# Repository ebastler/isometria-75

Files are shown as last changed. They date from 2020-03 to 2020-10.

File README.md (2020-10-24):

# isometria<sup>75</sup>

The first prototype is sitting on my desk and works perfectly - clearance for weights and battery is currently wrong, so the intended battery will not fit in the case.

----
 
 The name isometria<sup>75</sup> has it's origin in the greek noun ἰσομετρία (in latin letters: isometria), meaning "equality of measure" [[1]](http://perseus.uchicago.edu/cgi-bin/philologic/getobject.pl?c.35:6:59.LSJ). This word ended up being included in various languages, among them english (isometric), with the same meaning. I chose it for two reasons - because this keyboard is only available in an ISO layout (sorry ANSI users - for once it is ne ANSI avail), but also, because I paid attention to only use u/4 spaces throughout my board. You will have a hard time finding any distance on it that's not a multiple of 4.75 mm.

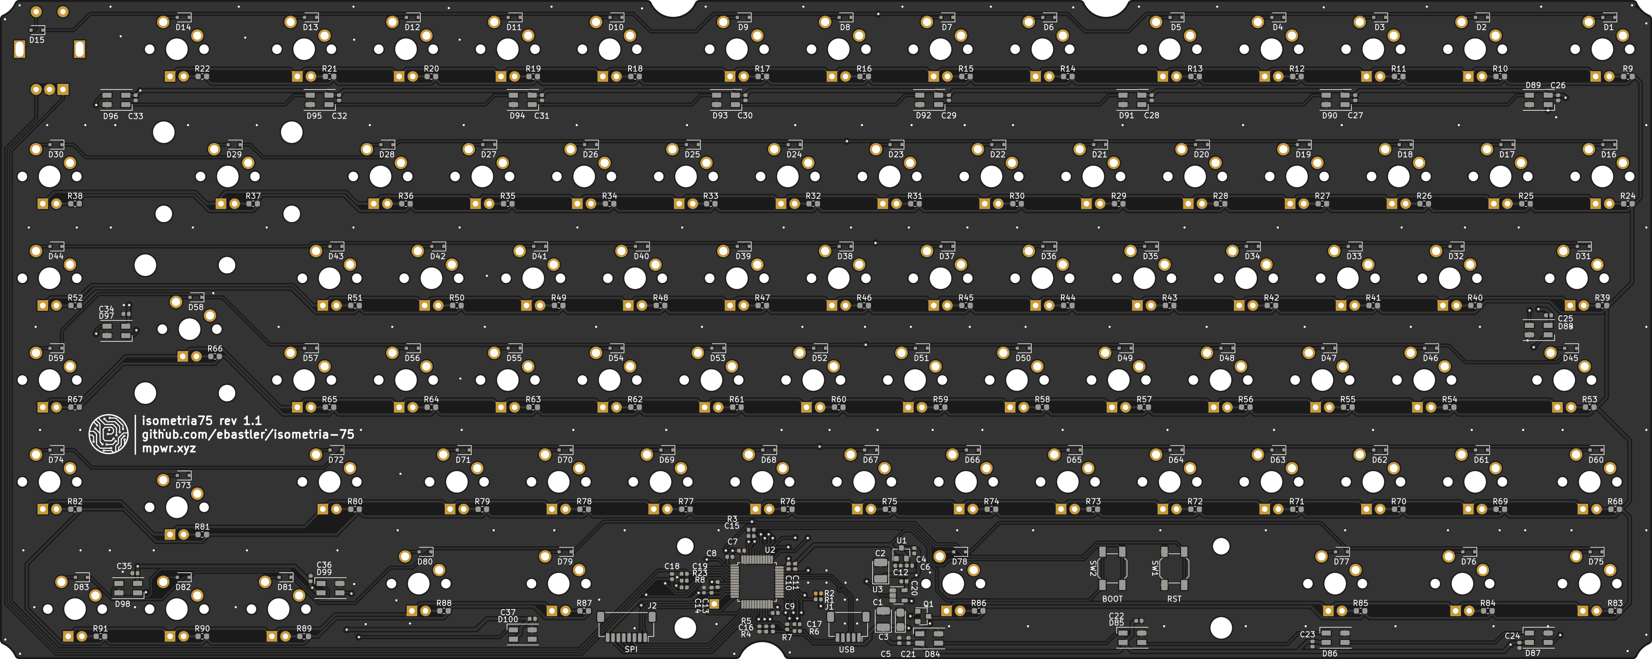
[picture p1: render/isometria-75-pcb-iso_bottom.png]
pcb_bottom
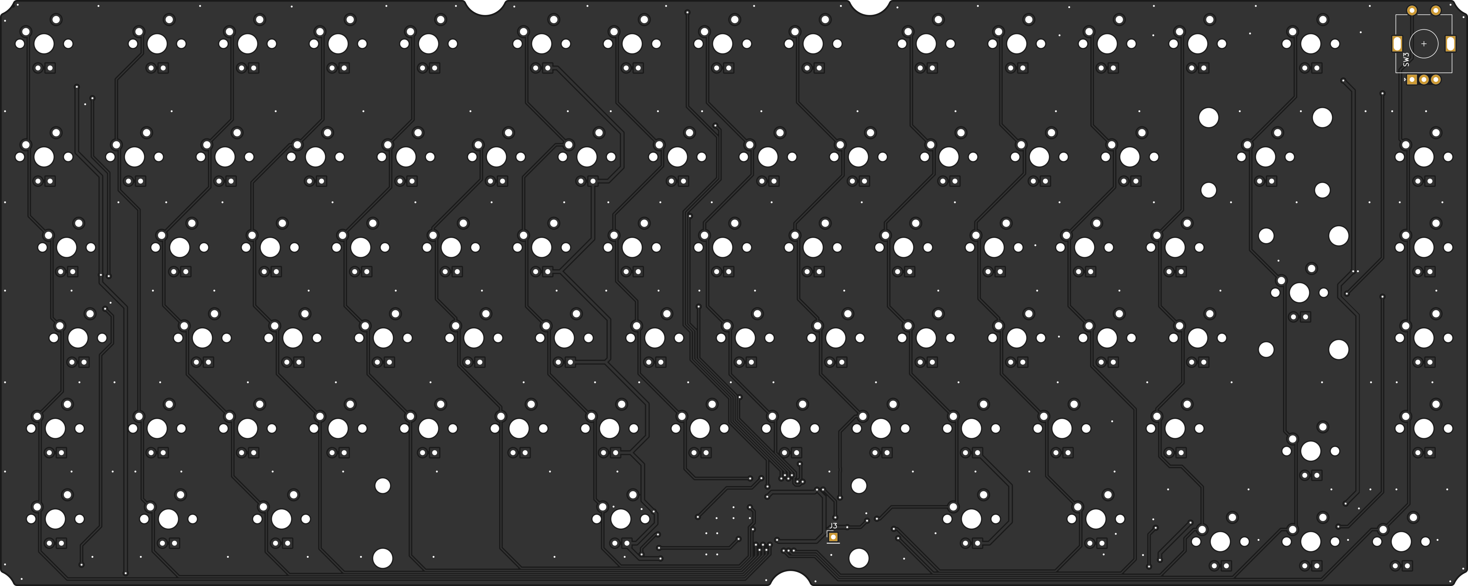
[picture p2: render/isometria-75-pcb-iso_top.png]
pcb_top
|||
|:---:|:---:|
|overview_top|detail_top|
|overview_rearside|overview_side|

 ## Features
 * CNC'd top shell with integrated 3 mm plate (obviously, with cutouts for switch retention and PCB mount stabs)
 * 6.8° typing angle
 * The PCB is equipped to fit 82 cherry MX-style switches
 * One 3 mm LED per switch (monochrome, dimmable only as one group)
 * 17 SK6812 Mini can be soldered to the bottom of the board for underglow
 * Fits either a battery-management or a simple USB-C daughterboard ([Repo link](https://github.com/ebastler/unified-usb-pcb))
 * A rotary encoder sits in the top right corner and the push-button is wired to the controller (Row 0 Column 15)
 * The USB-C connector is placed on a small PCB on it's own, which can be replaced by a battery management board
 * Sense wires to measure the input voltage and to check if the battery is currently being charged
 * A STM32F072CBT6 controller with native crystal-less USB and a lot of IO for various things
 * An SPI interface is wired to a second connector, allowing for a SPI Bluetooth LE board to be added
 * One leftover GPIO is available on a header - if you want to add something yourself

## Design
The PCB uses a key spacing of 19 mm (instead of the default 19.05), and all delimiters between key-blocks, or keys and the border of the case are 4.75 or 9.5 mm wide. This allows for a pleasantly homogenous design, which earned the keyboard it's name. Sadly, this layout requires a 1.5u right shift, which very few sets include. 

The bottom shell breaks the minimalist design of the top shell a little, with "stepped" faces. While the design originated from the need to make it easily millable on a 3 axis CNC, I appreciate the fact that it makes the board visually a bit more interesting.

## Geekhack project thread
https://geekhack.org/index.php?topic=106060.msg2896354

## FAQ:
 * Where can I buy this?

   I'm afraid there will not be any groupbuy nor will it be stocked at some reseller - All files are open source though, feel free to order a batch of PCBs and a case yourself - or improve it!

 * When will there be an ANSI version?

   Even though I planned not to do ANSI, I actually went with multi-layout for v2! Stay tuned!

 * Why did you clone the Evolv/Satisfaction?
 
   I made my own design choices, and designed everything from scratch - however the evolv heavily influenced my design. I fell in love with it the first time I saw it, but it had a few things I dislike. So I decided to mostly adopt it's layout with some changes, and design a case which follows my design ideals - ending up with a (visually) very similar top enclosure - The standalone-features of the evolv are it's premium materials, construction and generative design, and I did not include either.

For any other questions, or problems with my board (if you decided to build one yourself) - feel free to contact me. I'm idling around and occasionally check my PMs on freenode (ebastler), am active on reddit (the_ebastler) and on discord (ebastler#8966).

## Big thanks to:
 - ai03 for both his [great tutorial](https://wiki.ai03.me/books/pcb-design/chapter/pcb-designer-guide) as well as his various footprints I used in my design - I don't know if I had been able to design this without his help.
 - The awesome people on grabcad for the [MX switch](https://grabcad.com/library/cherry-mx-switches-mx-1), [Cherry Stab](https://grabcad.com/library/cherry-mx-stabilizer-mx-1) and [pushbutton](https://grabcad.com/library/5mm-button-switch-1) models, [JST SH models](https://grabcad.com/library/jst-sh-smd-connectors-1/details?folder_id=3903823) and [WS2812 Mini models](https://grabcad.com/library/smd-ws2812b-led-1) which made my design a whole lot easier, and my renders prettier.
  - People on the MechKeys and Mechanische Tastaturen Deutschland discord servers who tirelessly answered my questions - from the noobiest to the most complicated ones.
  - [Propagandalf1](https://github.com/Propagandalf1) for all the advise, criticism and ideas for improvement
  - Pseudoephedrin and Lux for checking my PCB layouts for errors
  - Hendrik for milling my proto

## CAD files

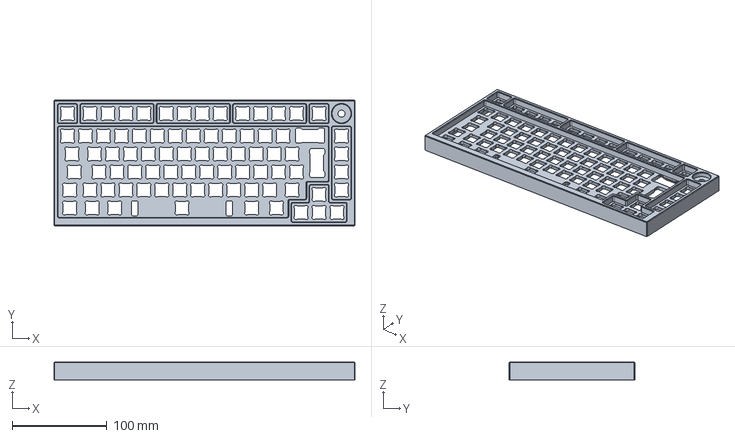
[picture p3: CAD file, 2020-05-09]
isometria-75-case-iso/fab/isometria-75-top.step
318.2 x 133.0 x 19.0 mm

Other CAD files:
isometria-75-case-iso/fab/isometria-75-bottom.step

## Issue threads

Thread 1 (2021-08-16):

BOM and CPL Files in XLS, XLSX or in CSV format

Ardakilic, 2021-08-16:
Hello,

I want to print the PCB from JLCPCB, however, the BOM format on the repository is in XML format, which is not accepted by them.

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

Can you share the BOM and CPL files in a way which JLCPCB can understand please, so I can get the PCB's SMD components such as IC pre-assembled?

Thanks, kind regards,

Closed 2021-08-17.

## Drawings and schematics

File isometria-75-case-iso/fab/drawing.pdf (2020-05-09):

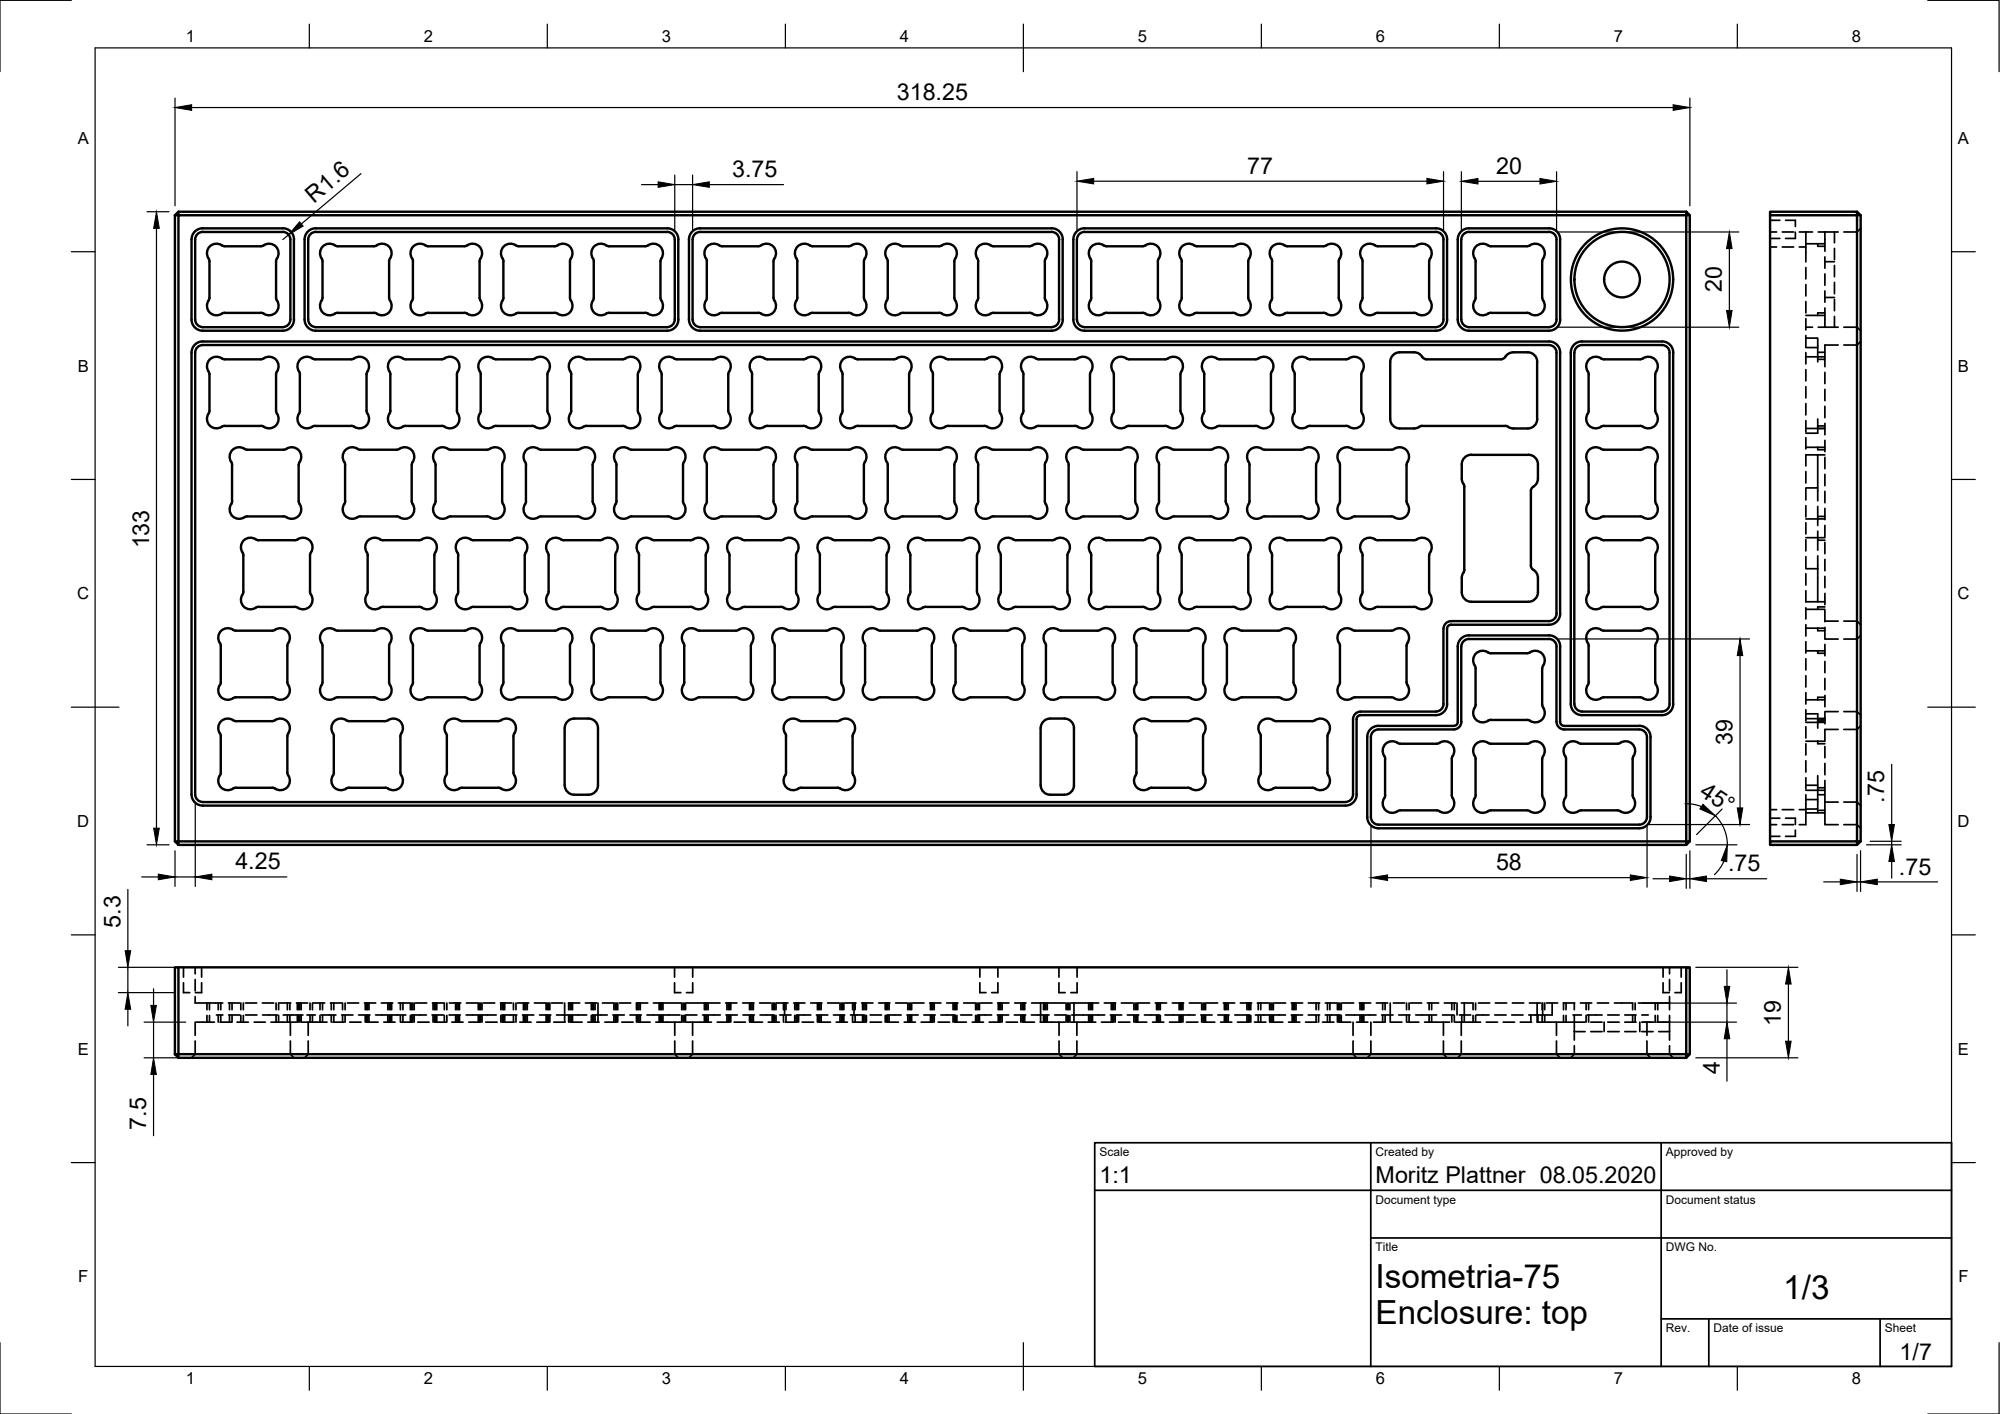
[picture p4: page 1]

Scale 1:1 | Created by Moritz Plattner 08.05.2020 | Approved by

Document type | Document status

Title Enclosure: top | DWG No. 1/3 Isometria-75

Rev. | Date of issue | Sheet

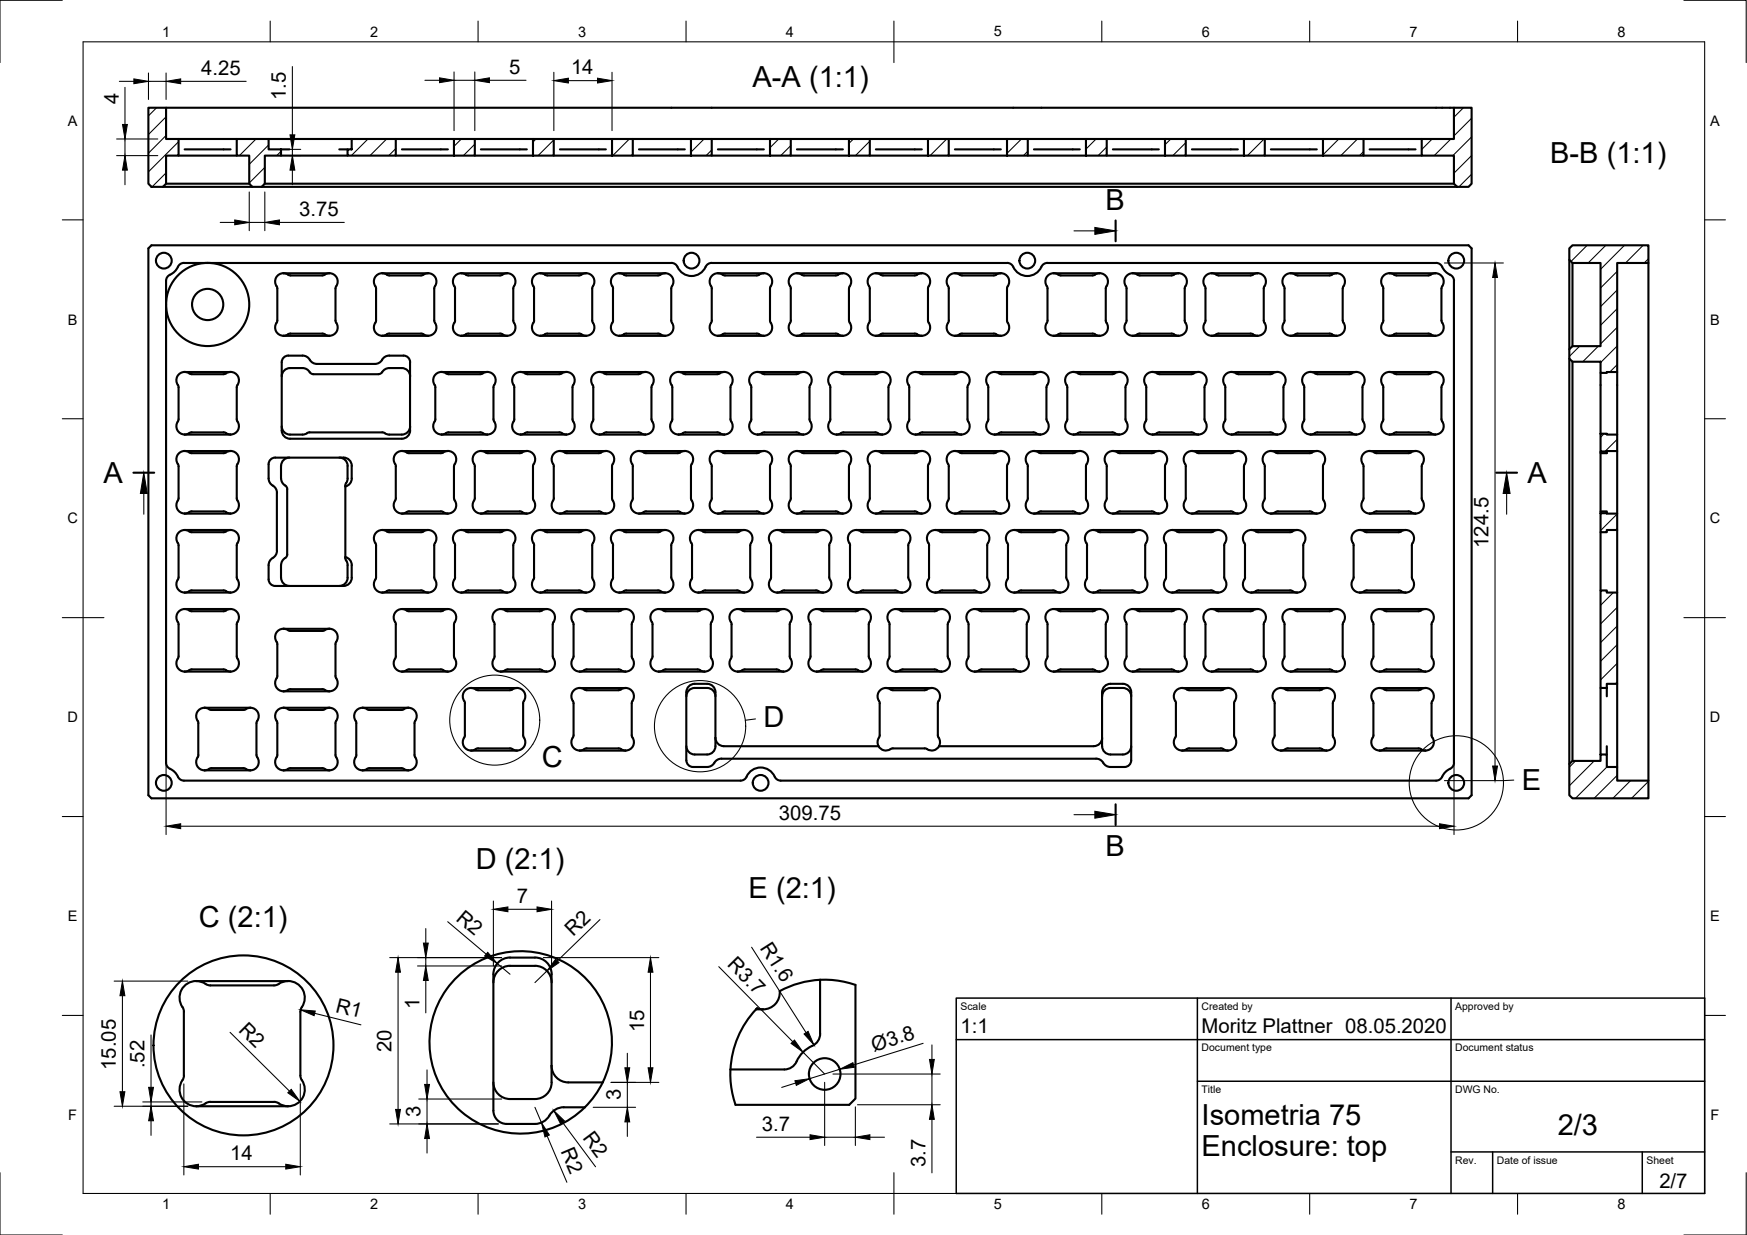
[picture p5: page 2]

Scale 1:1 | Created by Moritz Plattner 08.05.2020 | Approved by

Document type | Document status

Title | DWG No. 2/3 Isometria 75

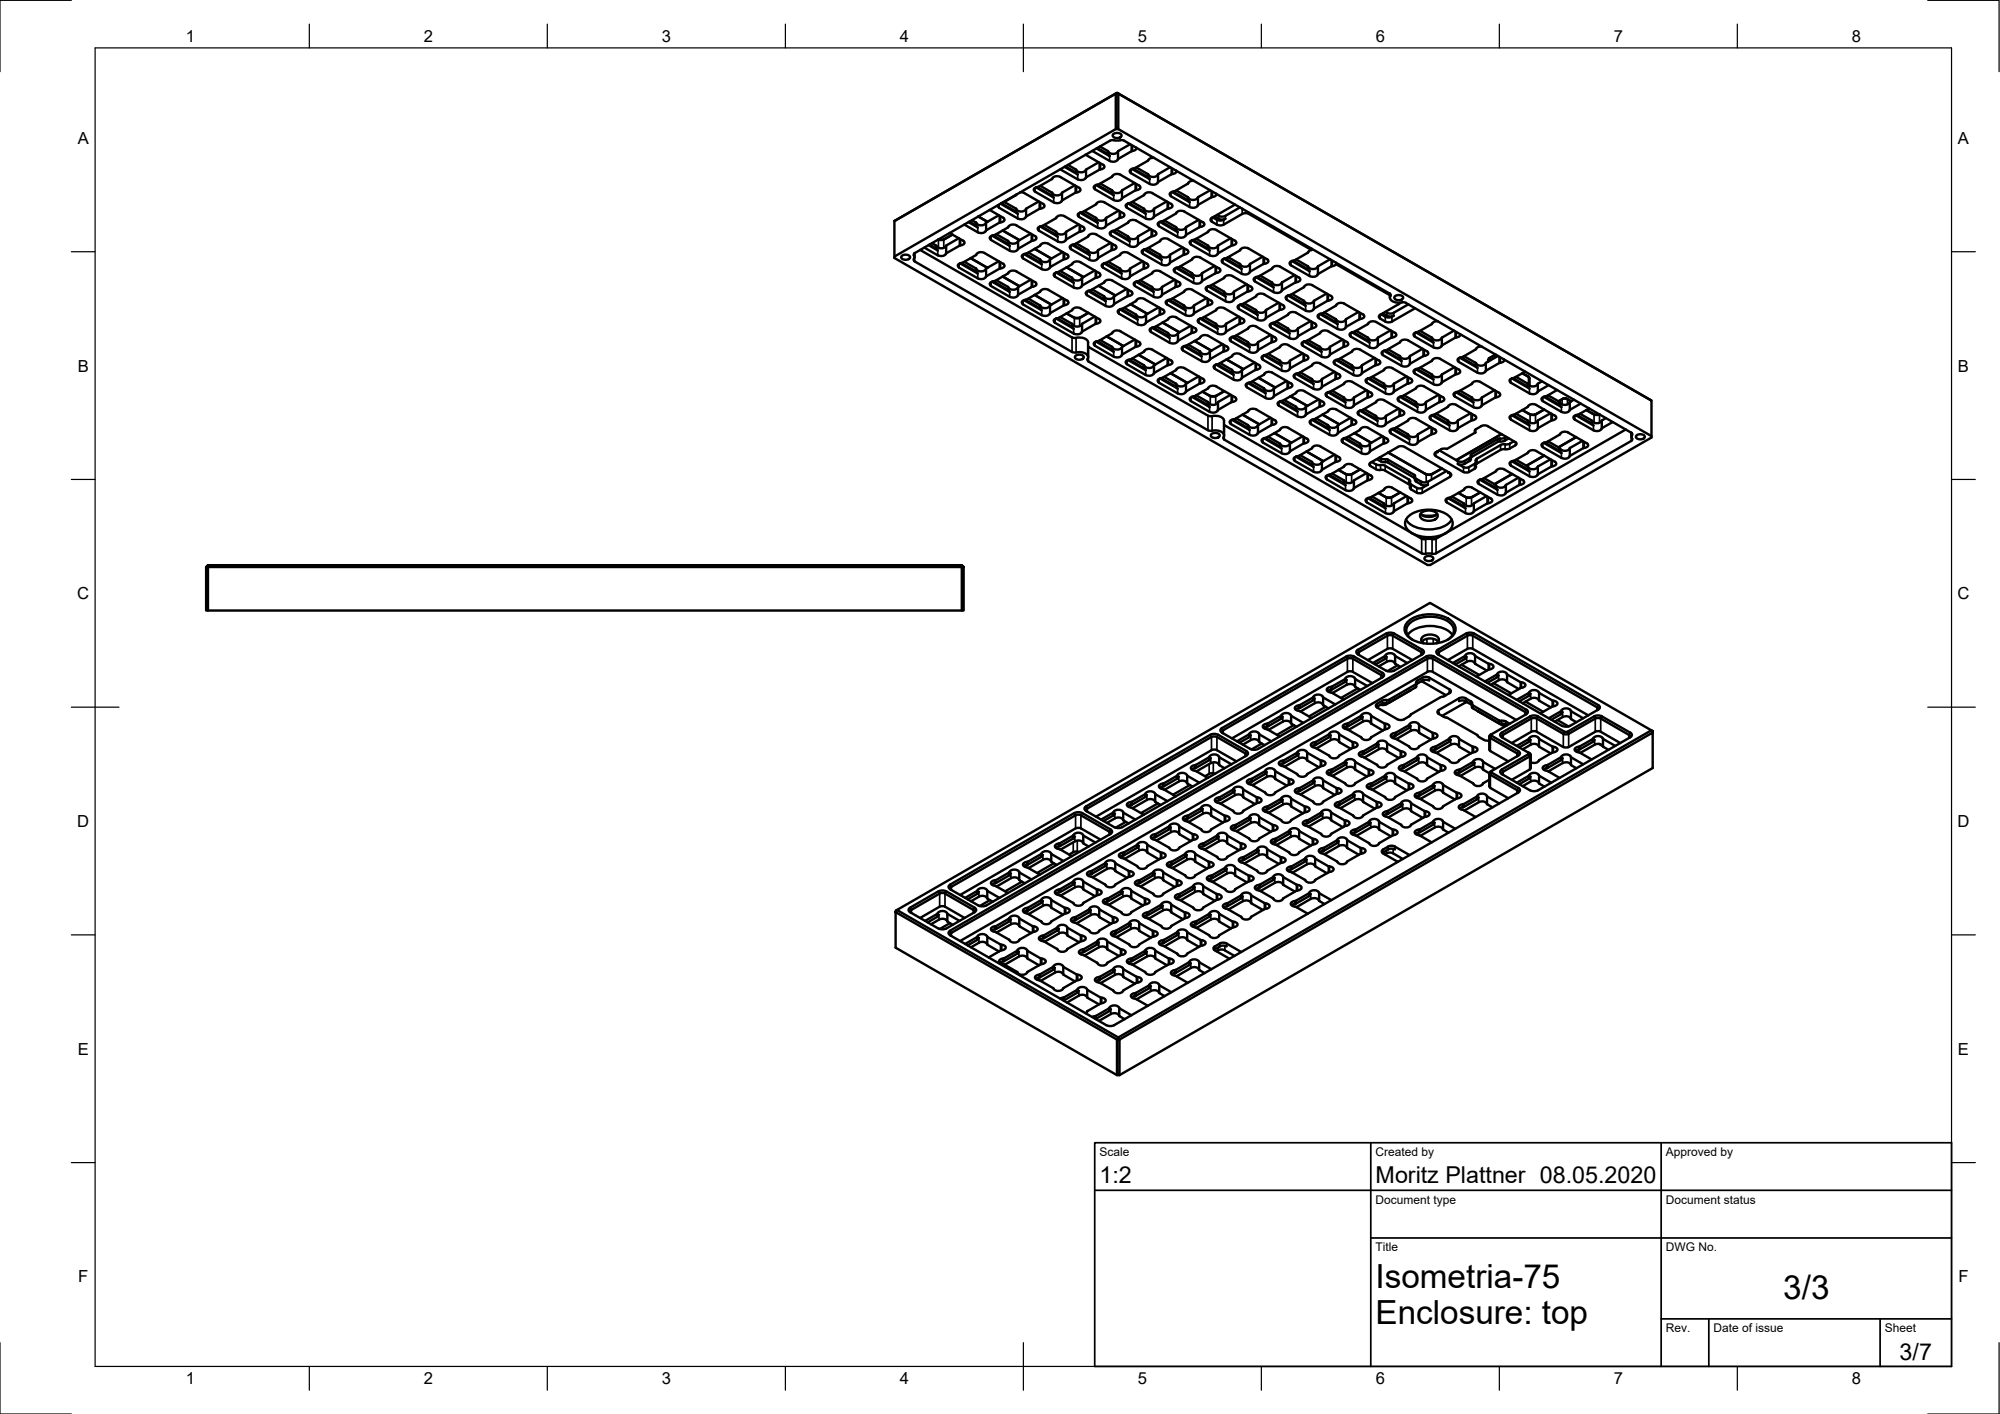
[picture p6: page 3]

Scale 1:2 | Created by Moritz Plattner 08.05.2020 | Approved by

Document type | Document status

Title | DWG No. 3/3 Isometria-75

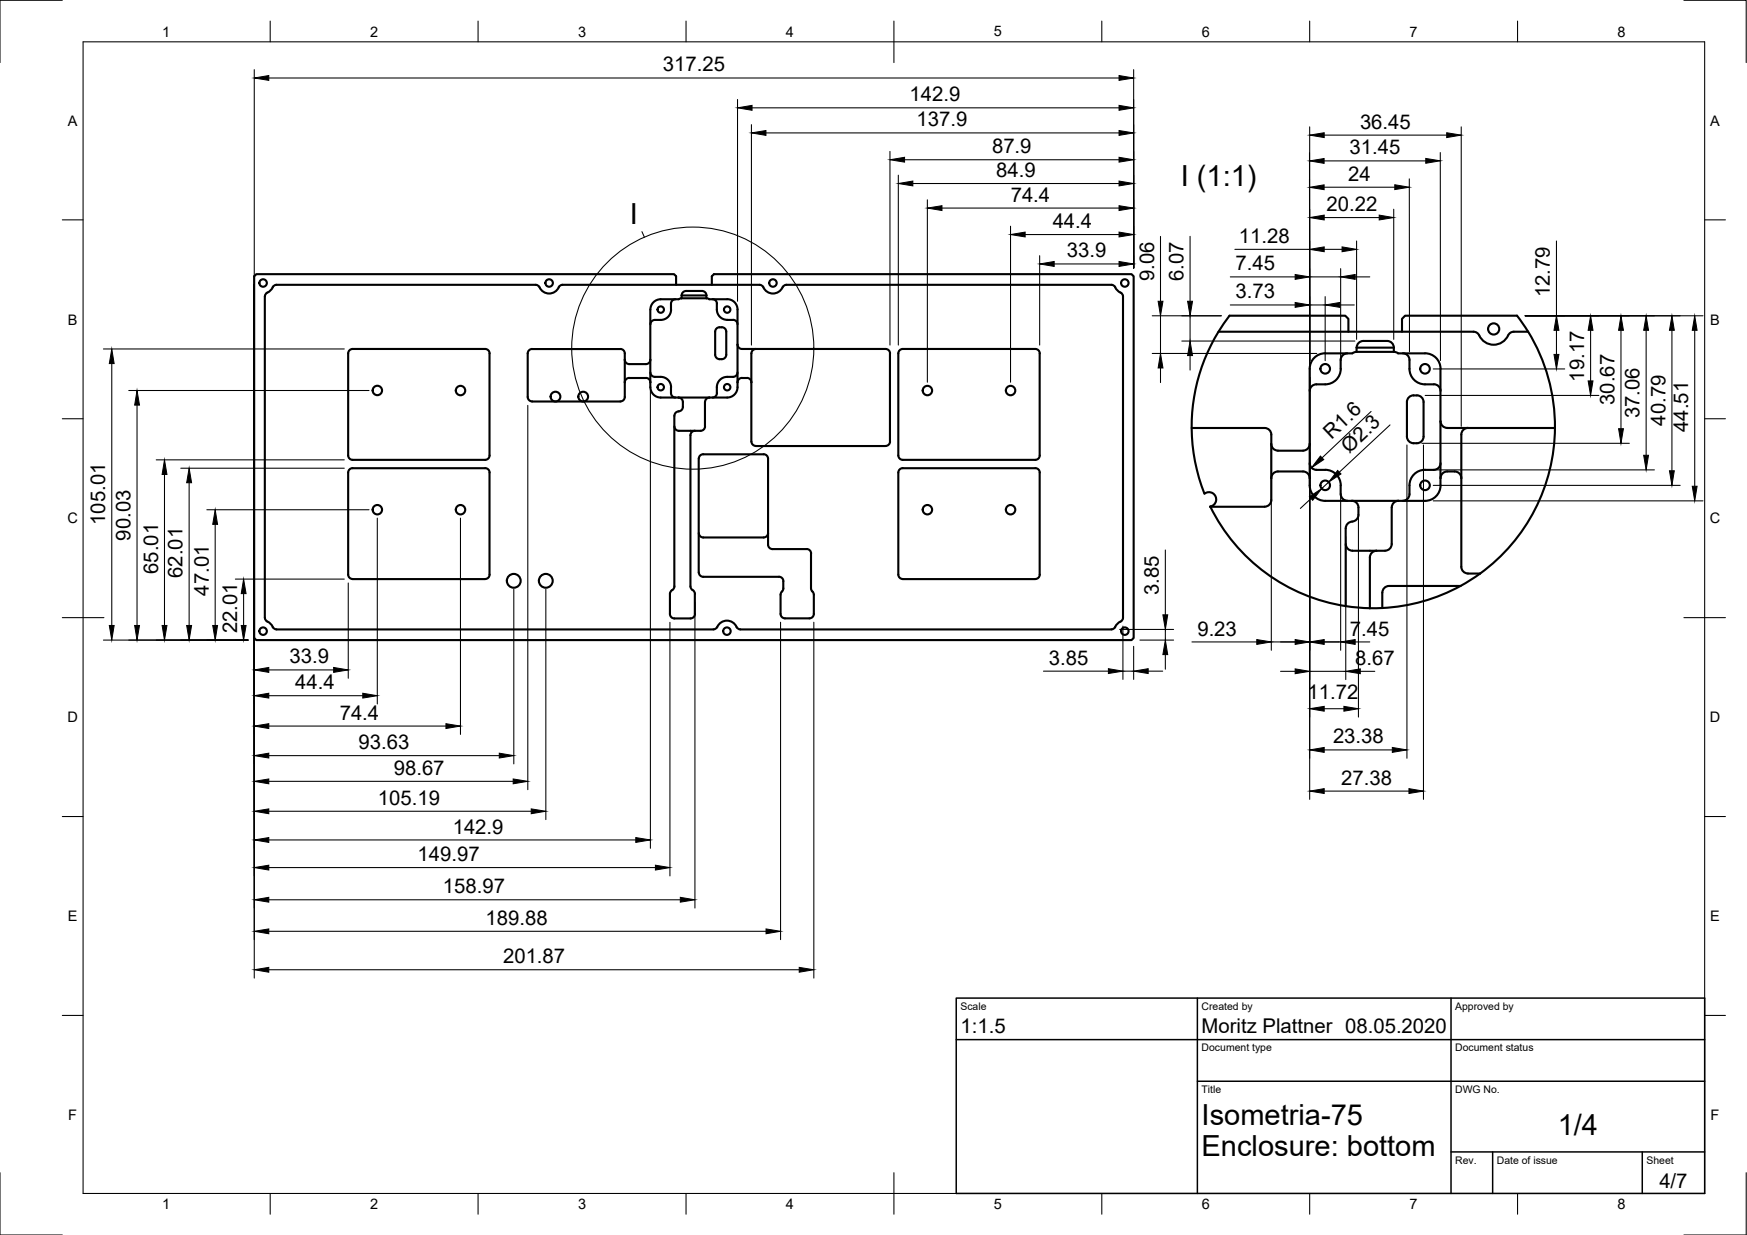
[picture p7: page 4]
8 BCDEF; ABCDEF; Moritz Plattner 3.85

Scale | Created by 08.05.2020 | Approved by

Document type | Document status

Title Enclosure: bottom | DWG No. 1/4 Isometria-75

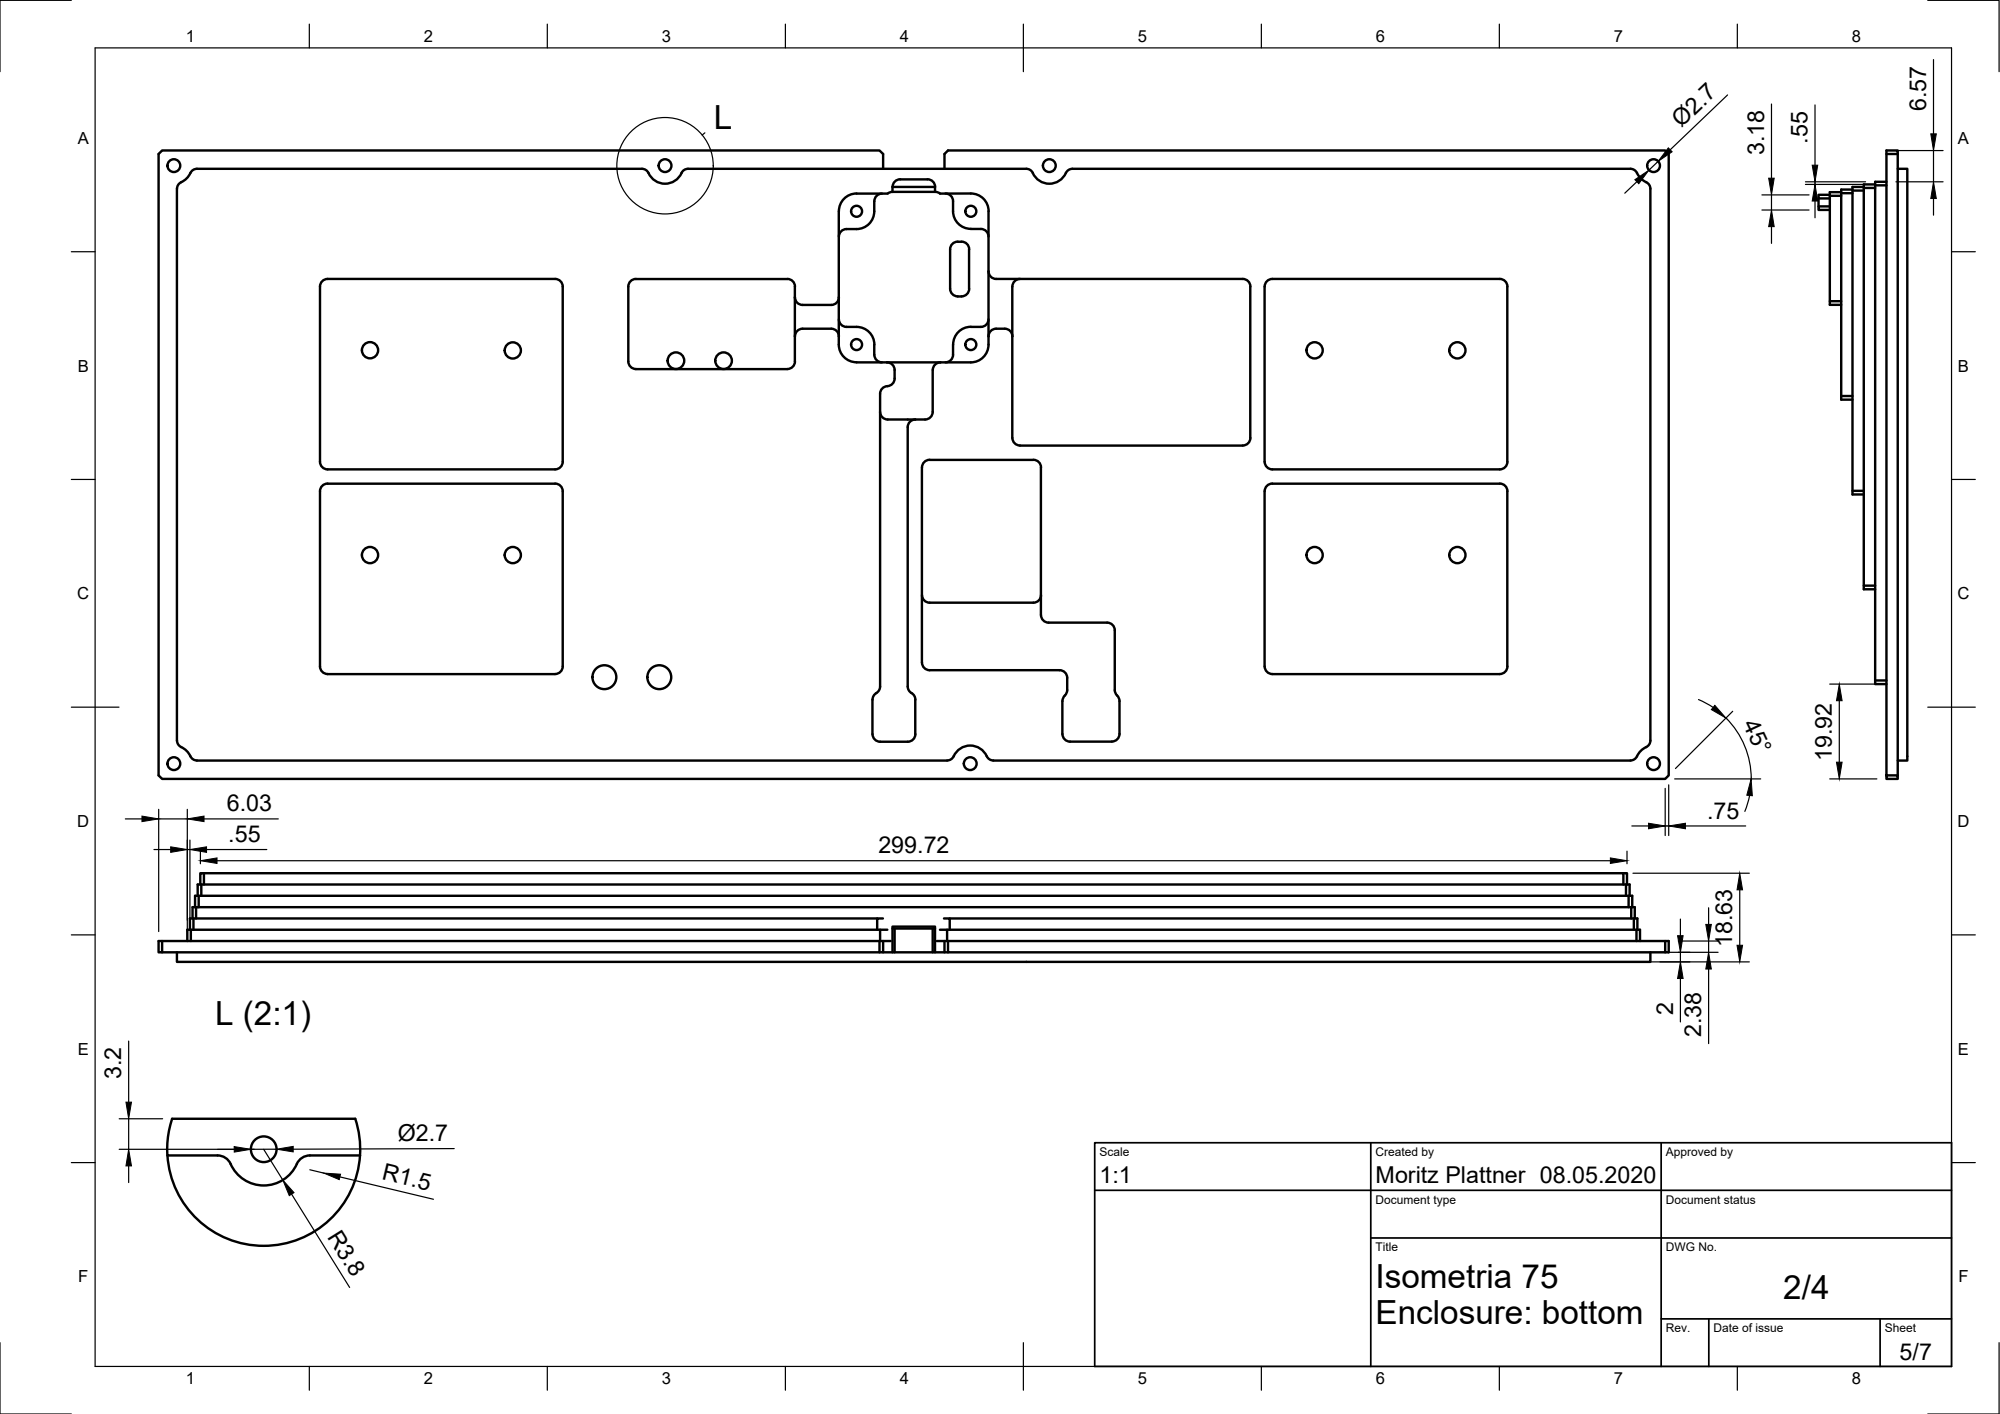
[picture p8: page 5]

Scale 1:1 | Created by Moritz Plattner 08.05.2020 | Approved by

Document type | Document status

Title | DWG No. 2/4 Isometria 75

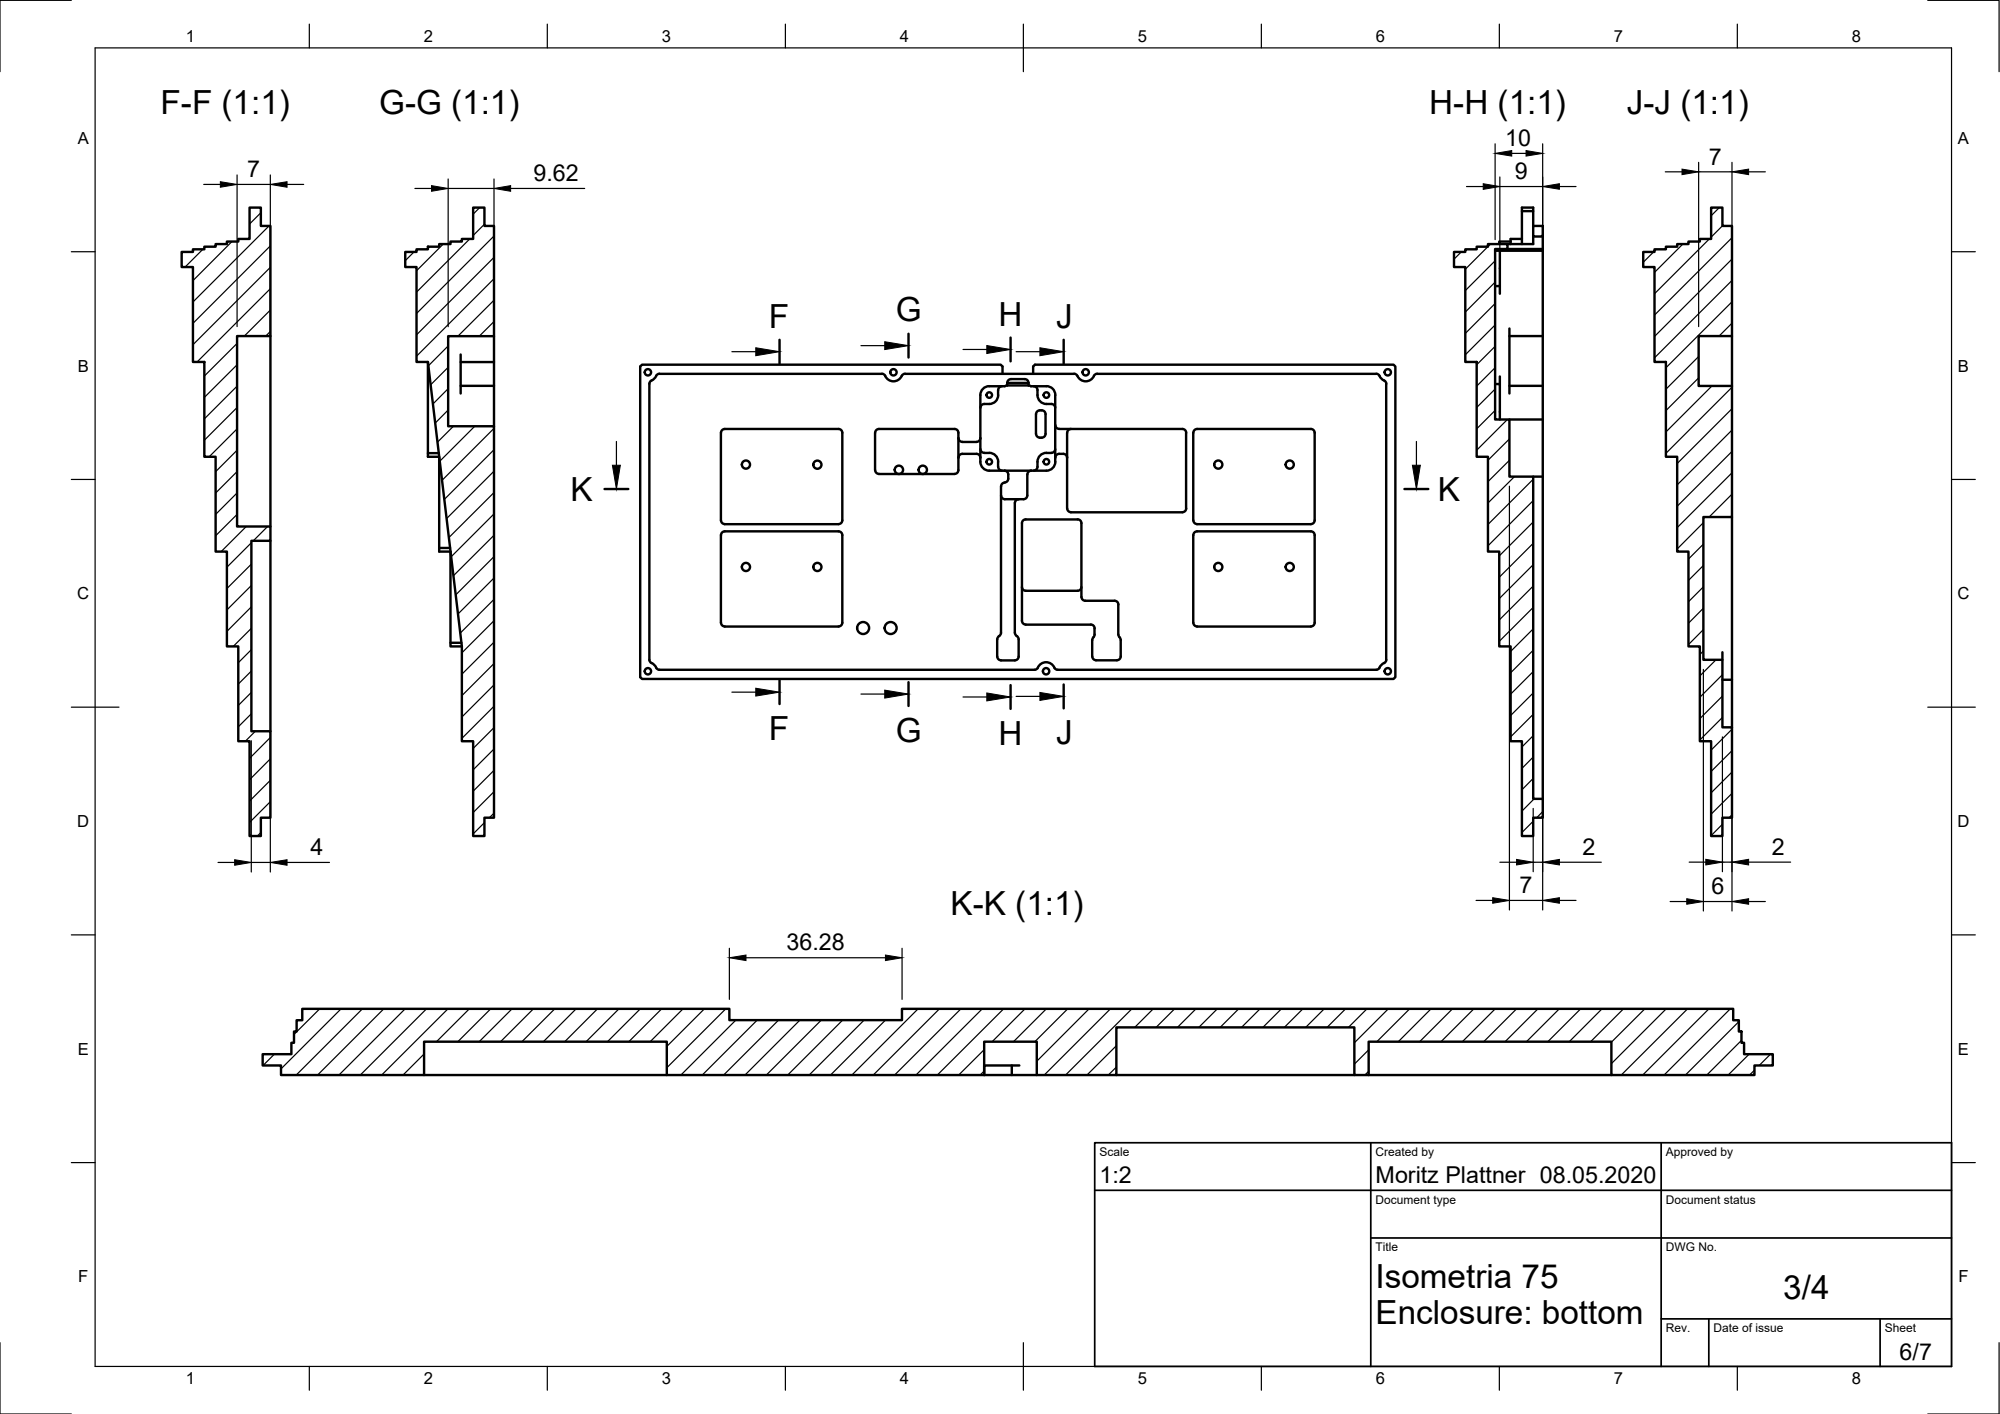
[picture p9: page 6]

Scale 1:2 | Created by Moritz Plattner 08.05.2020 | Approved by

Document type | Document status

Title | DWG No. 3/4 Isometria 75

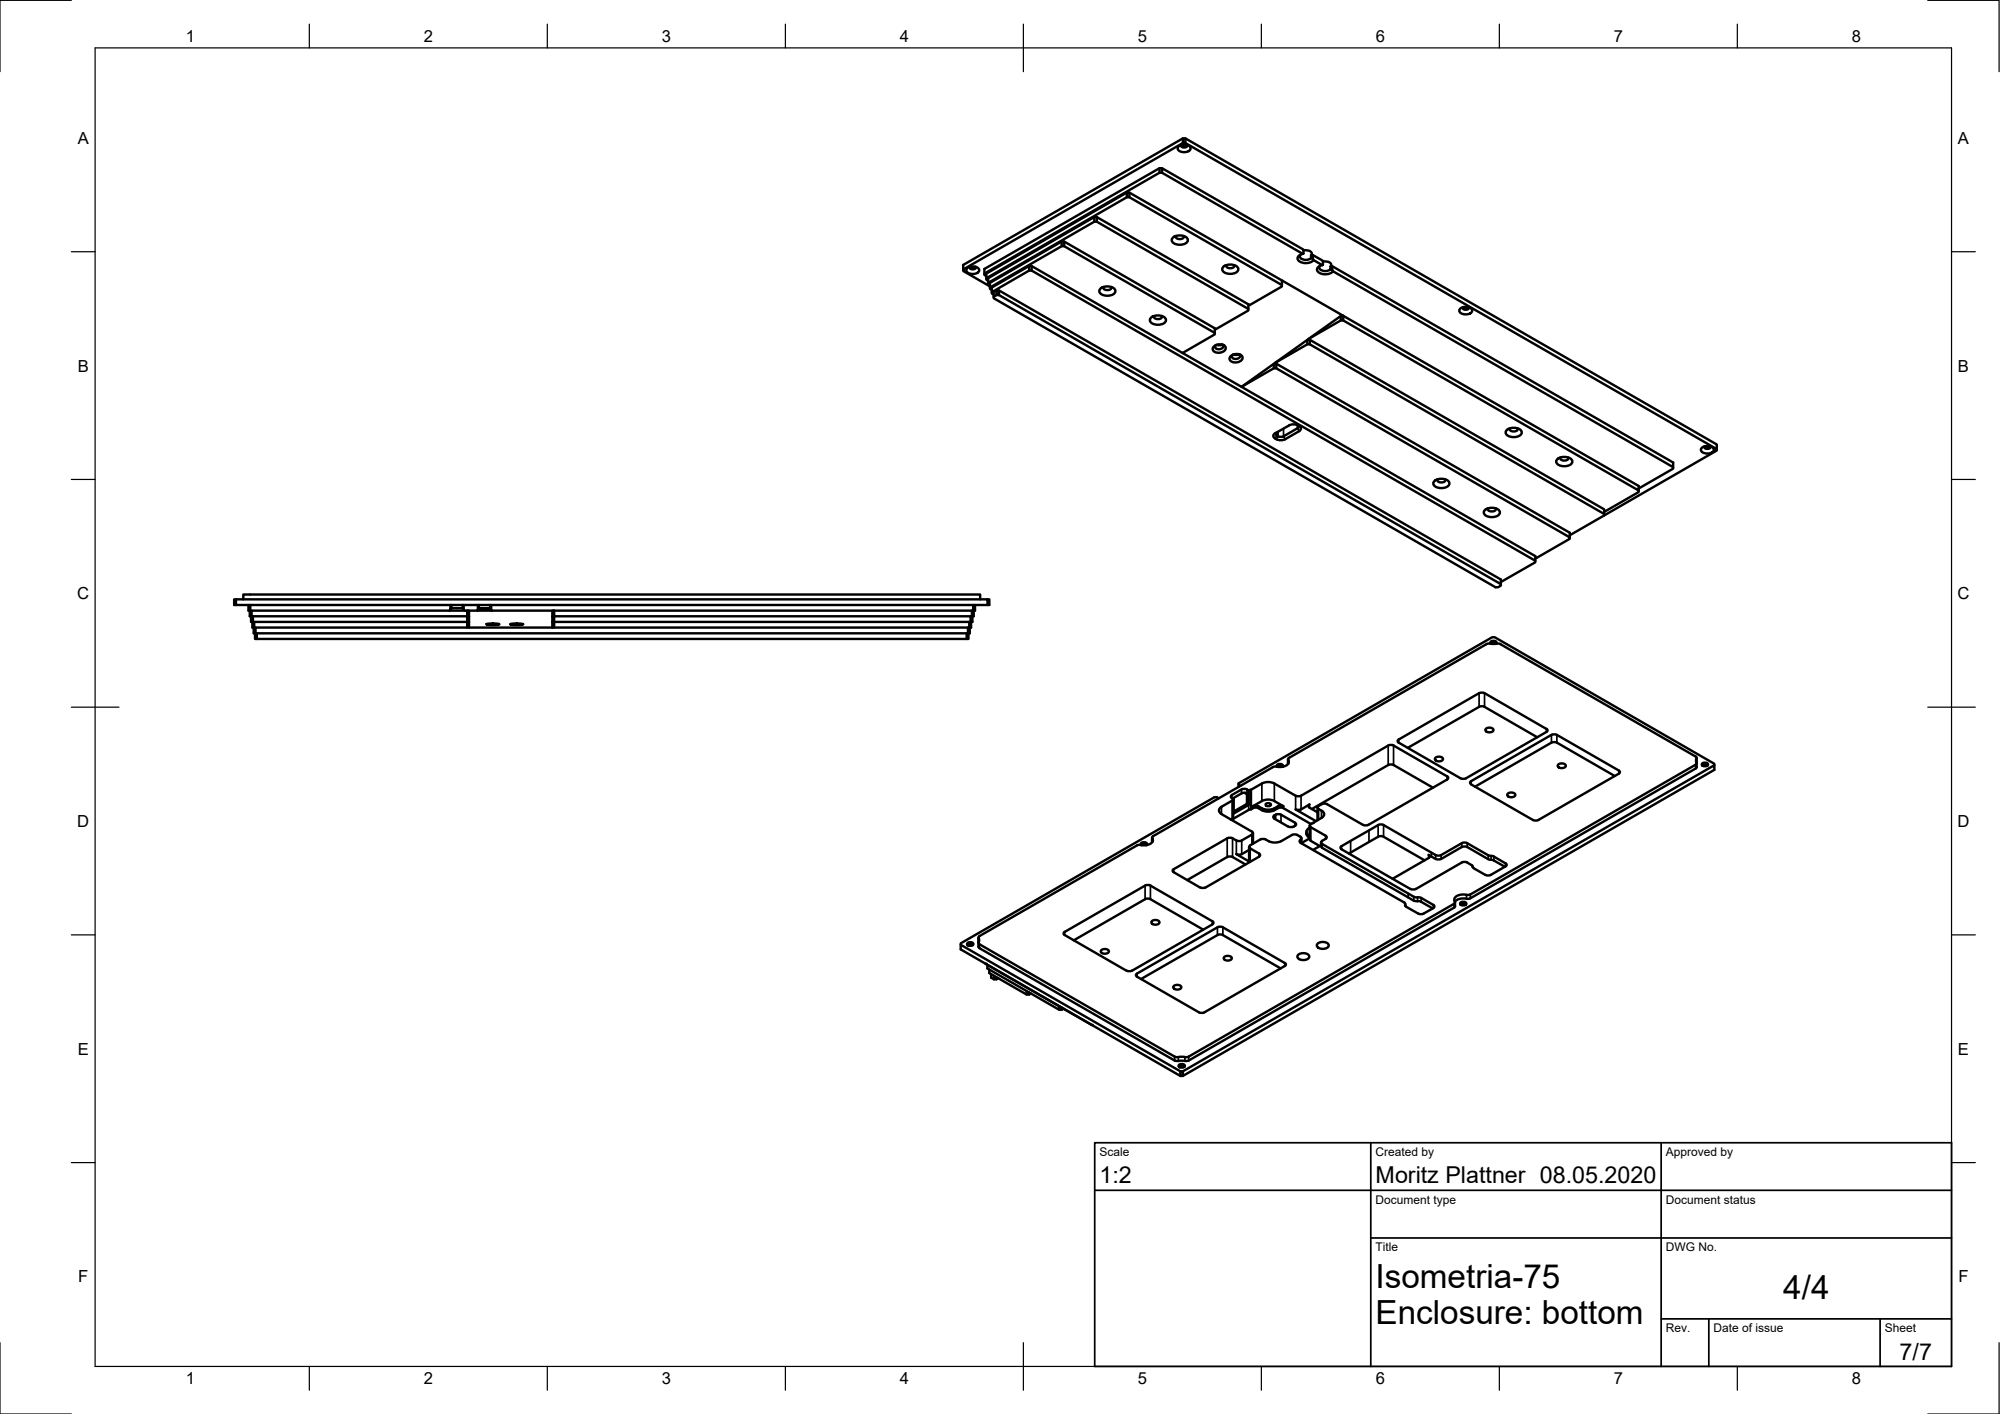
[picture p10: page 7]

Scale 1:2 | Created by Moritz Plattner 08.05.2020 | Approved by

Document type | Document status

Title | DWG No. 4/4 Isometria-75

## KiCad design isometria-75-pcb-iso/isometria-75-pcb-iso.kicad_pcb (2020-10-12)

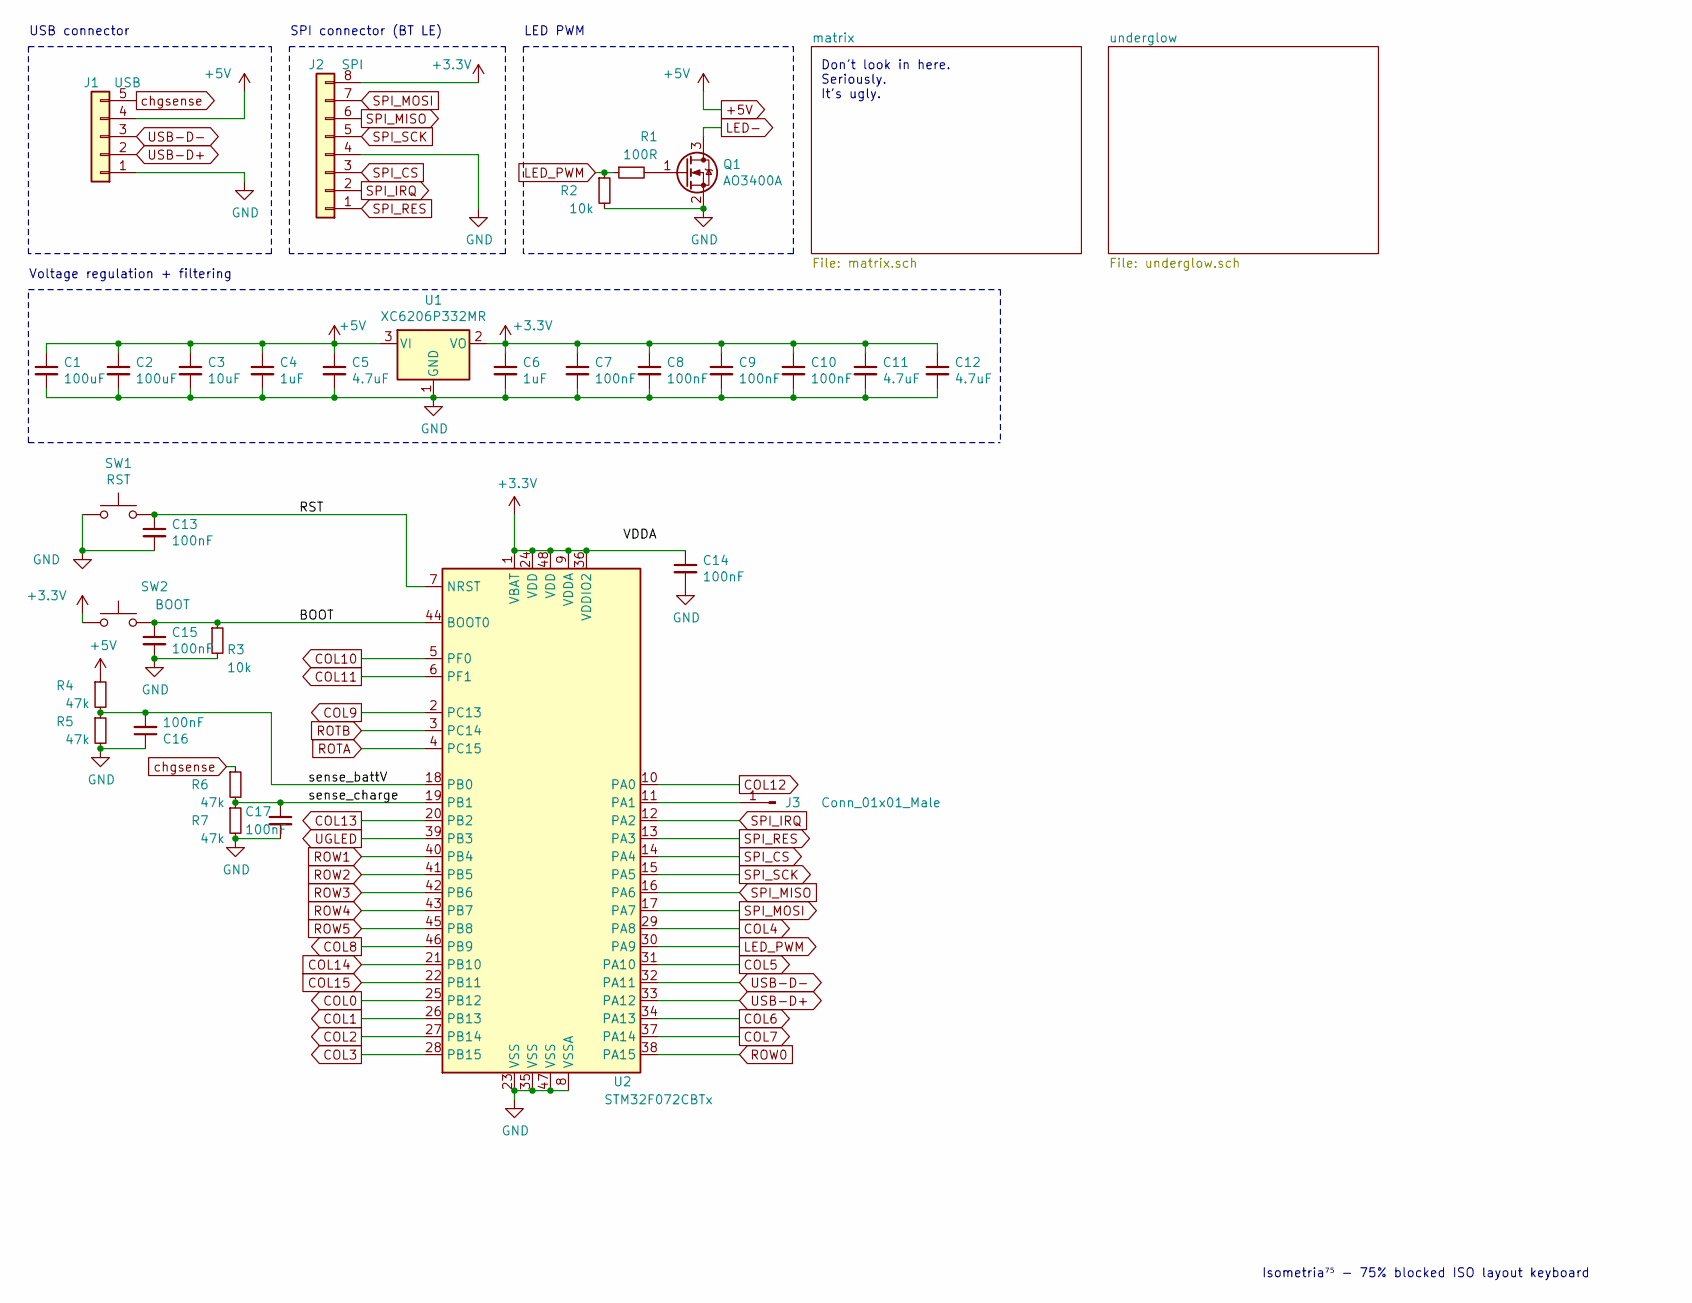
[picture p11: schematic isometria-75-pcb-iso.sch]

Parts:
C1, C2: 100uF; CP_EIA-3528-21_Kemet-B; LCSC C16133
C3: 10uF; CP_EIA-3216-18_Kemet-A; LCSC C7171
C4, C6: 1uF; C_0402_1005Metric; LCSC C52923
C5, C11, C12: 4.7uF; C_0402_1005Metric; LCSC C23733
C7, C8, C9, C10, C13, C14, C15, C16, C17: 100nF; C_0402_1005Metric; LCSC C1525
J1: USB; JST_SH_SM05B-SRSS-TB_1x05-1MP_P1.00mm_Horizontal
J2: SPI; JST_SH_SM08B-SRSS-TB_1x08-1MP_P1.00mm_Horizontal
J3: Conn_01x01_Male; PinHeader_1x01_P2.54mm_Vertical
Q1: AO3400A; SOT-23; LCSC C20917
R1: 100R; R_0402_1005Metric; LCSC C25076
R2, R3: 10k; R_0402_1005Metric; LCSC C25744
R4, R5, R6, R7: 47k; R_0402_1005Metric; LCSC C25792
SW1: RST; SW_SPST_SKQG_WithStem; LCSC C318886
SW2: BOOT; SW_SPST_SKQG_WithStem; LCSC C318886
U1: XC6206P332MR; SOT-23; LCSC C5446
U2: STM32F072CBTx; LQFP-48_7x7mm_P0.5mm; LCSC C81720

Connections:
+3V3: C6.1, C7.1, C8.1, C9.1, C10.1, C11.1, C12.1, C14.1, J2.8, SW2.1, U1.2 (VO), U2.1 (VBAT), U2.9 (VDDA), U2.24 (VDD), U2.36 (VDDIO2), U2.48 (VDD); also elsewhere on the board
+5V: C1.1, C2.1, C3.1, C4.1, C5.1, J1.4, R4.1, U1.3 (VI); also elsewhere on the board
/BOOT: C15.1, R3.1, SW2.2, U2.44 (BOOT0)
/RST: C13.1, SW1.2, U2.7 (NRST)
/sense_battV: C16.2, R4.2, R5.1, U2.18 (PB0)
/sense_charge: C17.1, R6.2, R7.1, U2.19 (PB1)
COL0: U2.25 (PB12); also elsewhere on the board
COL1: U2.26 (PB13); also elsewhere on the board
COL2: U2.27 (PB14); also elsewhere on the board
COL3: U2.28 (PB15); also elsewhere on the board
COL4: U2.29 (PA8); also elsewhere on the board
COL5: U2.31 (PA10); also elsewhere on the board
COL6: U2.34 (PA13); also elsewhere on the board
COL7: U2.37 (PA14); also elsewhere on the board
COL8: U2.46 (PB9); also elsewhere on the board
COL9: U2.2 (PC13); also elsewhere on the board
COL10: U2.5 (PF0); also elsewhere on the board
COL11: U2.6 (PF1); also elsewhere on the board
COL12: U2.10 (PA0); also elsewhere on the board
COL13: U2.20 (PB2); also elsewhere on the board
COL14: U2.21 (PB10); also elsewhere on the board
COL15: U2.22 (PB11); also elsewhere on the board
GND: C1.2, C2.2, C3.2, C4.2, C5.2, C6.2, C7.2, C8.2, C9.2, C10.2, C11.2, C12.2, C13.2, C14.2, C15.2, C16.1, C17.2, J1.1, J2.4, Q1.2 (S), R2.2, R3.2, R5.2, R7.2, SW1.1, U1.1 (GND), U2.8 (VSSA), U2.23 (VSS), U2.35 (VSS), U2.47 (VSS); also elsewhere on the board
LED-: Q1.3 (D); also elsewhere on the board
LED_PWM: R1.1, R2.1, U2.30 (PA9)
unnamed: J3.1, U2.11 (PA1)
unnamed: Q1.1 (G), R1.2
ROTA: U2.4 (PC15); also elsewhere on the board
ROTB: U2.3 (PC14); also elsewhere on the board
ROW0: U2.38 (PA15); also elsewhere on the board
ROW1: U2.40 (PB4); also elsewhere on the board
ROW2: U2.41 (PB5); also elsewhere on the board
ROW3: U2.42 (PB6); also elsewhere on the board
ROW4: U2.43 (PB7); also elsewhere on the board
ROW5: U2.45 (PB8); also elsewhere on the board
SPI_CS: J2.3, U2.14 (PA4)
SPI_IRQ: J2.2, U2.12 (PA2)
SPI_MISO: J2.6, U2.16 (PA6)
SPI_MOSI: J2.7, U2.17 (PA7)
SPI_RES: J2.1, U2.13 (PA3)
SPI_SCK: J2.5, U2.15 (PA5)
UGLED: U2.39 (PB3); also elsewhere on the board
USB-D+: J1.2, U2.33 (PA12)
USB-D-: J1.3, U2.32 (PA11)
chgsense: J1.5, R6.1

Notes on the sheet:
USB connector
SPI connector (BT LE)
Voltage regulation + filtering
LED PWM
Don't look in here. Seriously. It's ugly.
Isometria⁷⁵ - 75% blocked ISO layout keyboard

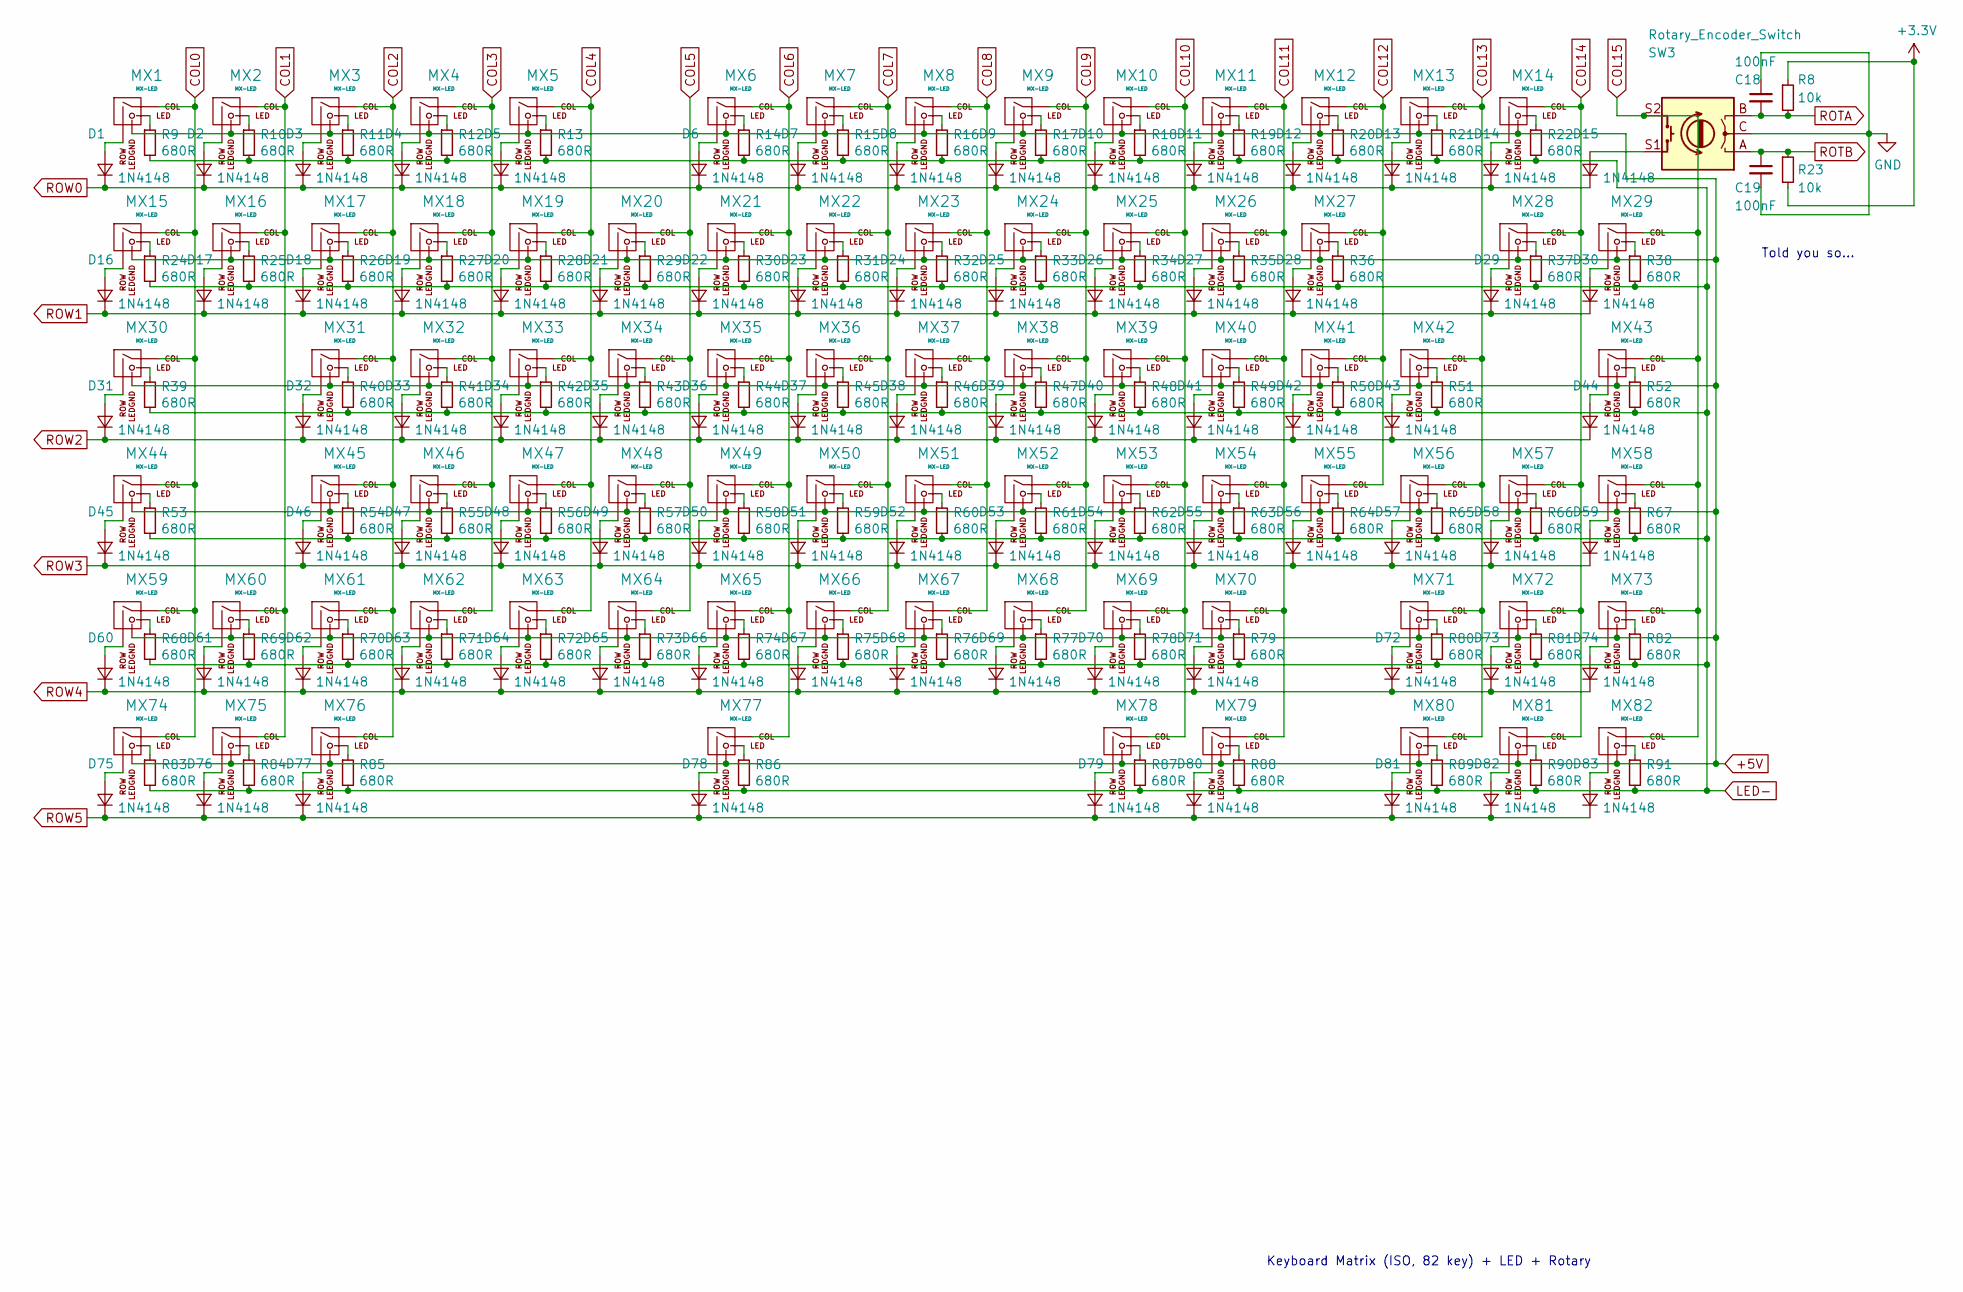
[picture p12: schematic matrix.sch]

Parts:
C18, C19: 100nF; C_0402_1005Metric; LCSC C1525
D1, D2, D3, D4, D5, D6, D7, D8, D9, D10, D11, D12, D13, D14, D15, D16, D17, D18, D19, D20, D21, D22, D23, D24, D25, D26, D27, D28, D29, D30, D31, D32, D33, D34, D35, D36, D37, D38, D39, D40, D41, D42, D43, D44, D45, D46, D47, D48, D49, D50, D51, D52, D53, D54, D55, D56, D57, D58, D59, D60, D61, D62, D63, D64, D65, D66, D67, D68, D69, D70, D71, D72, D73, D74, D75, D76, D77, D78, D79, D80, D81, D82, D83: 1N4148; D_SOD-323F; LCSC C2128
MX1, MX2, MX3, MX4, MX5, MX6, MX7, MX8, MX9, MX10, MX11, MX12, MX13, MX14, MX15, MX16, MX17, MX18, MX19, MX20, MX21, MX22, MX23, MX24, MX25, MX26, MX27, MX29, MX31, MX32, MX33, MX34, MX35, MX36, MX37, MX38, MX39, MX40, MX41, MX42, MX43, MX45, MX46, MX47, MX48, MX49, MX50, MX51, MX52, MX53, MX54, MX55, MX56, MX58, MX60, MX61, MX62, MX63, MX64, MX65, MX66, MX67, MX68, MX69, MX70, MX72, MX73, MX80, MX81, MX82: MX-LED; MXOnly-1U
MX28: MX-LED; MXOnly-2U-ReversedStabilizers
MX30, MX71, MX78: MX-LED; MXOnly-1.5U
MX44: MX-LED; MXOnly-1.75U
MX57: MX-LED; MXOnly-ISO
MX59, MX74, MX75, MX76, MX79: MX-LED; MXOnly-1.25U
MX77: MX-LED; MXOnly-6.25U
R8, R23: 10k; R_0402_1005Metric; LCSC C25744
R9, R10, R11, R12, R13, R14, R15, R16, R17, R18, R19, R20, R21, R22, R24, R25, R26, R27, R28, R29, R30, R31, R32, R33, R34, R35, R36, R37, R38, R39, R40, R41, R42, R43, R44, R45, R46, R47, R48, R49, R50, R51, R52, R53, R54, R55, R56, R57, R58, R59, R60, R61, R62, R63, R64, R65, R66, R67, R68, R69, R70, R71, R72, R73, R74, R75, R76, R77, R78, R79, R80, R81, R82, R83, R84, R85, R86, R87, R88, R89, R90, R91: 680R; R_0603_1608Metric; LCSC C23228
SW3: Rotary_Encoder_Switch; RotaryEncoder_Alps_EC11E-Switch_Vertical_H20mm

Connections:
+3V3: R8.1, R23.2; also elsewhere on the board
+5V: MX1.4 (LEDGND), MX2.4 (LEDGND), MX3.4 (LEDGND), MX4.4 (LEDGND), MX5.4 (LEDGND), MX6.4 (LEDGND), MX7.4 (LEDGND), MX8.4 (LEDGND), MX9.4 (LEDGND), MX10.4 (LEDGND), MX11.4 (LEDGND), MX12.4 (LEDGND), MX13.4 (LEDGND), MX14.4 (LEDGND), MX15.4 (LEDGND), MX16.4 (LEDGND), MX17.4 (LEDGND), MX18.4 (LEDGND), MX19.4 (LEDGND), MX20.4 (LEDGND), MX21.4 (LEDGND), MX22.4 (LEDGND), MX23.4 (LEDGND), MX24.4 (LEDGND), MX25.4 (LEDGND), MX26.4 (LEDGND), MX27.4 (LEDGND), MX28.4 (LEDGND), MX29.4 (LEDGND), MX30.4 (LEDGND), MX31.4 (LEDGND), MX32.4 (LEDGND), MX33.4 (LEDGND), MX34.4 (LEDGND), MX35.4 (LEDGND), MX36.4 (LEDGND), MX37.4 (LEDGND), MX38.4 (LEDGND), MX39.4 (LEDGND), MX40.4 (LEDGND), MX41.4 (LEDGND), MX42.4 (LEDGND), MX43.4 (LEDGND), MX44.4 (LEDGND), MX45.4 (LEDGND), MX46.4 (LEDGND), MX47.4 (LEDGND), MX48.4 (LEDGND), MX49.4 (LEDGND), MX50.4 (LEDGND), MX51.4 (LEDGND), MX52.4 (LEDGND), MX53.4 (LEDGND), MX54.4 (LEDGND), MX55.4 (LEDGND), MX56.4 (LEDGND), MX57.4 (LEDGND), MX58.4 (LEDGND), MX59.4 (LEDGND), MX60.4 (LEDGND), MX61.4 (LEDGND), MX62.4 (LEDGND), MX63.4 (LEDGND), MX64.4 (LEDGND), MX65.4 (LEDGND), MX66.4 (LEDGND), MX67.4 (LEDGND), MX68.4 (LEDGND), MX69.4 (LEDGND), MX70.4 (LEDGND), MX71.4 (LEDGND), MX72.4 (LEDGND), MX73.4 (LEDGND), MX74.4 (LEDGND), MX75.4 (LEDGND), MX76.4 (LEDGND), MX77.4 (LEDGND), MX78.4 (LEDGND), MX79.4 (LEDGND), MX80.4 (LEDGND), MX81.4 (LEDGND), MX82.4 (LEDGND); also elsewhere on the board
COL0: MX1.1 (COL), MX15.1 (COL), MX30.1 (COL), MX44.1 (COL), MX59.1 (COL), MX74.1 (COL); also elsewhere on the board
COL1: MX2.1 (COL), MX16.1 (COL), MX60.1 (COL), MX75.1 (COL); also elsewhere on the board
COL2: MX3.1 (COL), MX17.1 (COL), MX31.1 (COL), MX45.1 (COL), MX61.1 (COL), MX76.1 (COL); also elsewhere on the board
COL3: MX4.1 (COL), MX18.1 (COL), MX32.1 (COL), MX46.1 (COL), MX62.1 (COL); also elsewhere on the board
COL4: MX5.1 (COL), MX19.1 (COL), MX33.1 (COL), MX47.1 (COL), MX63.1 (COL); also elsewhere on the board
COL5: MX20.1 (COL), MX34.1 (COL), MX48.1 (COL), MX64.1 (COL); also elsewhere on the board
COL6: MX6.1 (COL), MX21.1 (COL), MX35.1 (COL), MX49.1 (COL), MX65.1 (COL), MX77.1 (COL); also elsewhere on the board
COL7: MX7.1 (COL), MX22.1 (COL), MX36.1 (COL), MX50.1 (COL), MX66.1 (COL); also elsewhere on the board
COL8: MX8.1 (COL), MX23.1 (COL), MX37.1 (COL), MX51.1 (COL), MX67.1 (COL); also elsewhere on the board
COL9: MX9.1 (COL), MX24.1 (COL), MX38.1 (COL), MX52.1 (COL), MX68.1 (COL); also elsewhere on the board
COL10: MX10.1 (COL), MX25.1 (COL), MX39.1 (COL), MX53.1 (COL), MX69.1 (COL), MX78.1 (COL); also elsewhere on the board
COL11: MX11.1 (COL), MX26.1 (COL), MX40.1 (COL), MX54.1 (COL), MX70.1 (COL), MX79.1 (COL); also elsewhere on the board
COL12: MX12.1 (COL), MX27.1 (COL), MX41.1 (COL), MX55.1 (COL); also elsewhere on the board
COL13: MX13.1 (COL), MX42.1 (COL), MX56.1 (COL), MX71.1 (COL), MX80.1 (COL); also elsewhere on the board
COL14: MX14.1 (COL), MX28.1 (COL), MX57.1 (COL), MX72.1 (COL), MX81.1 (COL); also elsewhere on the board
COL15: MX29.1 (COL), MX43.1 (COL), MX58.1 (COL), MX73.1 (COL), MX82.1 (COL), SW3.S2; also elsewhere on the board
GND: C18.1, C19.2, SW3.C; also elsewhere on the board
LED-: R9.2, R10.2, R11.2, R12.2, R13.2, R14.2, R15.2, R16.2, R17.2, R18.2, R19.2, R20.2, R21.2, R22.2, R24.2, R25.2, R26.2, R27.2, R28.2, R29.2, R30.2, R31.2, R32.2, R33.2, R34.2, R35.2, R36.2, R37.2, R38.2, R39.2, R40.2, R41.2, R42.2, R43.2, R44.2, R45.2, R46.2, R47.2, R48.2, R49.2, R50.2, R51.2, R52.2, R53.2, R54.2, R55.2, R56.2, R57.2, R58.2, R59.2, R60.2, R61.2, R62.2, R63.2, R64.2, R65.2, R66.2, R67.2, R68.2, R69.2, R70.2, R71.2, R72.2, R73.2, R74.2, R75.2, R76.2, R77.2, R78.2, R79.2, R80.2, R81.2, R82.2, R83.2, R84.2, R85.2, R86.2, R87.2, R88.2, R89.2, R90.2, R91.2; also elsewhere on the board
unnamed: D1.2 (A), MX1.2 (ROW)
unnamed: D2.2 (A), MX2.2 (ROW)
unnamed: D3.2 (A), MX3.2 (ROW)
unnamed: D4.2 (A), MX4.2 (ROW)
unnamed: D5.2 (A), MX5.2 (ROW)
unnamed: D6.2 (A), MX6.2 (ROW)
unnamed: D7.2 (A), MX7.2 (ROW)
unnamed: D8.2 (A), MX8.2 (ROW)
unnamed: D9.2 (A), MX9.2 (ROW)
unnamed: D10.2 (A), MX10.2 (ROW)
unnamed: D11.2 (A), MX11.2 (ROW)
unnamed: D12.2 (A), MX12.2 (ROW)
unnamed: D13.2 (A), MX13.2 (ROW)
unnamed: D14.2 (A), MX14.2 (ROW)
unnamed: D15.2 (A), SW3.S1
unnamed: D16.2 (A), MX15.2 (ROW)
unnamed: D17.2 (A), MX16.2 (ROW)
unnamed: D18.2 (A), MX17.2 (ROW)
unnamed: D19.2 (A), MX18.2 (ROW)
unnamed: D20.2 (A), MX19.2 (ROW)
unnamed: D21.2 (A), MX20.2 (ROW)
unnamed: D22.2 (A), MX21.2 (ROW)
unnamed: D23.2 (A), MX22.2 (ROW)
unnamed: D24.2 (A), MX23.2 (ROW)
unnamed: D25.2 (A), MX24.2 (ROW)
unnamed: D26.2 (A), MX25.2 (ROW)
unnamed: D27.2 (A), MX26.2 (ROW)
unnamed: D28.2 (A), MX27.2 (ROW)
unnamed: D29.2 (A), MX28.2 (ROW)
unnamed: D30.2 (A), MX29.2 (ROW)
unnamed: D31.2 (A), MX30.2 (ROW)
unnamed: D32.2 (A), MX31.2 (ROW)
unnamed: D33.2 (A), MX32.2 (ROW)
unnamed: D34.2 (A), MX33.2 (ROW)
unnamed: D35.2 (A), MX34.2 (ROW)
unnamed: D36.2 (A), MX35.2 (ROW)
unnamed: D37.2 (A), MX36.2 (ROW)
unnamed: D38.2 (A), MX37.2 (ROW)
unnamed: D39.2 (A), MX38.2 (ROW)
unnamed: D40.2 (A), MX39.2 (ROW)
unnamed: D41.2 (A), MX40.2 (ROW)
unnamed: D42.2 (A), MX41.2 (ROW)
unnamed: D43.2 (A), MX42.2 (ROW)
unnamed: D44.2 (A), MX43.2 (ROW)
unnamed: D45.2 (A), MX44.2 (ROW)
unnamed: D46.2 (A), MX45.2 (ROW)
unnamed: D47.2 (A), MX46.2 (ROW)
unnamed: D48.2 (A), MX47.2 (ROW)
unnamed: D49.2 (A), MX48.2 (ROW)
unnamed: D50.2 (A), MX49.2 (ROW)
unnamed: D51.2 (A), MX50.2 (ROW)
unnamed: D52.2 (A), MX51.2 (ROW)
unnamed: D53.2 (A), MX52.2 (ROW)
unnamed: D54.2 (A), MX53.2 (ROW)
unnamed: D55.2 (A), MX54.2 (ROW)
unnamed: D56.2 (A), MX55.2 (ROW)
unnamed: D57.2 (A), MX56.2 (ROW)
unnamed: D58.2 (A), MX57.2 (ROW)
unnamed: D59.2 (A), MX58.2 (ROW)
unnamed: D60.2 (A), MX59.2 (ROW)
unnamed: D61.2 (A), MX60.2 (ROW)
unnamed: D62.2 (A), MX61.2 (ROW)
unnamed: D63.2 (A), MX62.2 (ROW)
unnamed: D64.2 (A), MX63.2 (ROW)
unnamed: D65.2 (A), MX64.2 (ROW)
unnamed: D66.2 (A), MX65.2 (ROW)
unnamed: D67.2 (A), MX66.2 (ROW)
unnamed: D68.2 (A), MX67.2 (ROW)
unnamed: D69.2 (A), MX68.2 (ROW)
unnamed: D70.2 (A), MX69.2 (ROW)
unnamed: D71.2 (A), MX70.2 (ROW)
unnamed: D72.2 (A), MX71.2 (ROW)
unnamed: D73.2 (A), MX72.2 (ROW)
unnamed: D74.2 (A), MX73.2 (ROW)
unnamed: D75.2 (A), MX74.2 (ROW)
unnamed: D76.2 (A), MX75.2 (ROW)
unnamed: D77.2 (A), MX76.2 (ROW)
unnamed: D78.2 (A), MX77.2 (ROW)
unnamed: D79.2 (A), MX78.2 (ROW)
unnamed: D80.2 (A), MX79.2 (ROW)
unnamed: D81.2 (A), MX80.2 (ROW)
unnamed: D82.2 (A), MX81.2 (ROW)
unnamed: D83.2 (A), MX82.2 (ROW)
unnamed: MX1.3 (LED), R9.1
unnamed: MX2.3 (LED), R10.1
unnamed: MX3.3 (LED), R11.1
unnamed: MX4.3 (LED), R12.1
unnamed: MX5.3 (LED), R13.1
unnamed: MX6.3 (LED), R14.1
unnamed: MX7.3 (LED), R15.1
unnamed: MX8.3 (LED), R16.1
unnamed: MX9.3 (LED), R17.1
unnamed: MX10.3 (LED), R18.1
unnamed: MX11.3 (LED), R19.1
unnamed: MX12.3 (LED), R20.1
unnamed: MX13.3 (LED), R21.1
unnamed: MX14.3 (LED), R22.1
unnamed: MX15.3 (LED), R24.1
unnamed: MX16.3 (LED), R25.1
unnamed: MX17.3 (LED), R26.1
unnamed: MX18.3 (LED), R27.1
unnamed: MX19.3 (LED), R28.1
unnamed: MX20.3 (LED), R29.1
unnamed: MX21.3 (LED), R30.1
unnamed: MX22.3 (LED), R31.1
unnamed: MX23.3 (LED), R32.1
unnamed: MX24.3 (LED), R33.1
unnamed: MX25.3 (LED), R34.1
unnamed: MX26.3 (LED), R35.1
unnamed: MX27.3 (LED), R36.1
unnamed: MX28.3 (LED), R37.1
unnamed: MX29.3 (LED), R38.1
unnamed: MX30.3 (LED), R39.1
unnamed: MX31.3 (LED), R40.1
unnamed: MX32.3 (LED), R41.1
unnamed: MX33.3 (LED), R42.1
unnamed: MX34.3 (LED), R43.1
unnamed: MX35.3 (LED), R44.1
unnamed: MX36.3 (LED), R45.1
unnamed: MX37.3 (LED), R46.1
unnamed: MX38.3 (LED), R47.1
unnamed: MX39.3 (LED), R48.1
unnamed: MX40.3 (LED), R49.1
unnamed: MX41.3 (LED), R50.1
unnamed: MX42.3 (LED), R51.1
unnamed: MX43.3 (LED), R52.1
unnamed: MX44.3 (LED), R53.1
unnamed: MX45.3 (LED), R54.1
unnamed: MX46.3 (LED), R55.1
unnamed: MX47.3 (LED), R56.1
unnamed: MX48.3 (LED), R57.1
unnamed: MX49.3 (LED), R58.1
unnamed: MX50.3 (LED), R59.1
unnamed: MX51.3 (LED), R60.1
unnamed: MX52.3 (LED), R61.1
unnamed: MX53.3 (LED), R62.1
unnamed: MX54.3 (LED), R63.1
unnamed: MX55.3 (LED), R64.1
unnamed: MX56.3 (LED), R65.1
unnamed: MX57.3 (LED), R66.1
unnamed: MX58.3 (LED), R67.1
unnamed: MX59.3 (LED), R68.1
unnamed: MX60.3 (LED), R69.1
unnamed: MX61.3 (LED), R70.1
unnamed: MX62.3 (LED), R71.1
unnamed: MX63.3 (LED), R72.1
unnamed: MX64.3 (LED), R73.1
unnamed: MX65.3 (LED), R74.1
unnamed: MX66.3 (LED), R75.1
unnamed: MX67.3 (LED), R76.1
unnamed: MX68.3 (LED), R77.1
unnamed: MX69.3 (LED), R78.1
unnamed: MX70.3 (LED), R79.1
unnamed: MX71.3 (LED), R80.1
unnamed: MX72.3 (LED), R81.1
unnamed: MX73.3 (LED), R82.1
unnamed: MX74.3 (LED), R83.1
unnamed: MX75.3 (LED), R84.1
unnamed: MX76.3 (LED), R85.1
unnamed: MX77.3 (LED), R86.1
unnamed: MX78.3 (LED), R87.1
unnamed: MX79.3 (LED), R88.1
unnamed: MX80.3 (LED), R89.1
unnamed: MX81.3 (LED), R90.1
unnamed: MX82.3 (LED), R91.1
ROTA: C18.2, R8.2, SW3.B; also elsewhere on the board
ROTB: C19.1, R23.1, SW3.A; also elsewhere on the board
ROW0: D1.1 (K), D2.1 (K), D3.1 (K), D4.1 (K), D5.1 (K), D6.1 (K), D7.1 (K), D8.1 (K), D9.1 (K), D10.1 (K), D11.1 (K), D12.1 (K), D13.1 (K), D14.1 (K), D15.1 (K); also elsewhere on the board
ROW1: D16.1 (K), D17.1 (K), D18.1 (K), D19.1 (K), D20.1 (K), D21.1 (K), D22.1 (K), D23.1 (K), D24.1 (K), D25.1 (K), D26.1 (K), D27.1 (K), D28.1 (K), D29.1 (K), D30.1 (K); also elsewhere on the board
ROW2: D31.1 (K), D32.1 (K), D33.1 (K), D34.1 (K), D35.1 (K), D36.1 (K), D37.1 (K), D38.1 (K), D39.1 (K), D40.1 (K), D41.1 (K), D42.1 (K), D43.1 (K), D44.1 (K); also elsewhere on the board
ROW3: D45.1 (K), D46.1 (K), D47.1 (K), D48.1 (K), D49.1 (K), D50.1 (K), D51.1 (K), D52.1 (K), D53.1 (K), D54.1 (K), D55.1 (K), D56.1 (K), D57.1 (K), D58.1 (K), D59.1 (K); also elsewhere on the board
ROW4: D60.1 (K), D61.1 (K), D62.1 (K), D63.1 (K), D64.1 (K), D65.1 (K), D66.1 (K), D67.1 (K), D68.1 (K), D69.1 (K), D70.1 (K), D71.1 (K), D72.1 (K), D73.1 (K), D74.1 (K); also elsewhere on the board
ROW5: D75.1 (K), D76.1 (K), D77.1 (K), D78.1 (K), D79.1 (K), D80.1 (K), D81.1 (K), D82.1 (K), D83.1 (K); also elsewhere on the board

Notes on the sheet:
Told you so...
Keyboard Matrix (ISO, 82 key) + LED + Rotary

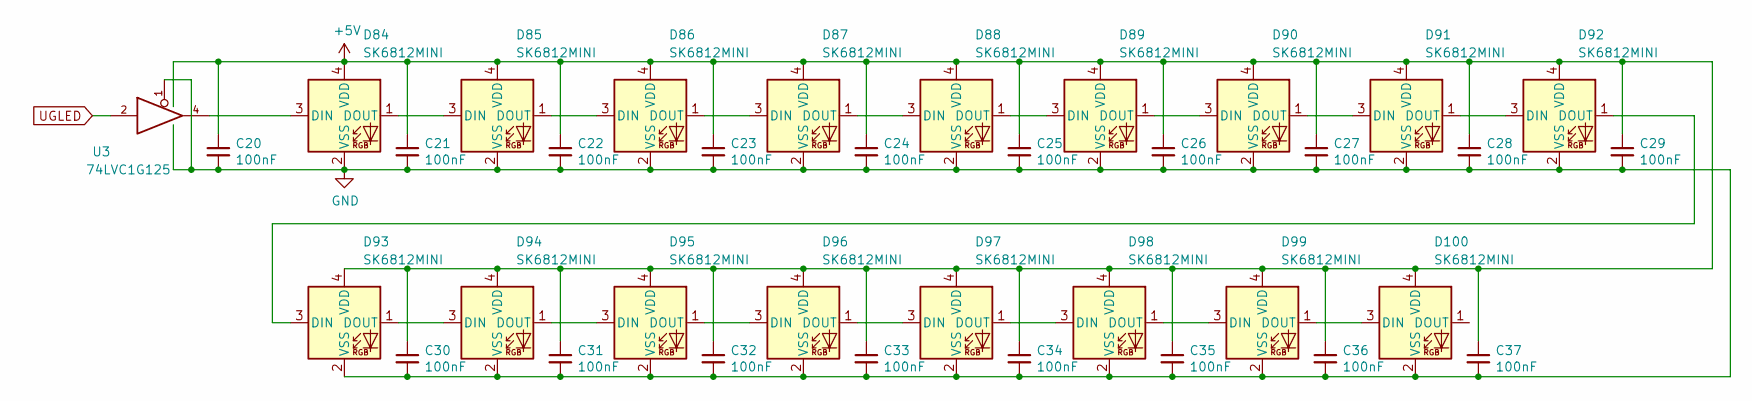
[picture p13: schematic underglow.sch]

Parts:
C20, C21, C22, C23, C24, C25, C26, C27, C28, C29, C30, C31, C32, C33, C34, C35, C36, C37: 100nF; C_0402_1005Metric; LCSC C1525
D84, D85, D86, D87, D88, D89, D90, D91, D92, D93, D94, D95, D96, D97, D98, D99, D100: SK6812MINI; LED_SK6812MINI_PLCC4_3.5x3.5mm_P1.75mm
U3: 74LVC1G125; SOT-23-5; LCSC C23654

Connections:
+5V: C20.1, C21.1, C22.1, C23.1, C24.1, C25.1, C26.1, C27.1, C28.1, C29.1, C30.1, C31.1, C32.1, C33.1, C34.1, C35.1, C36.1, C37.1, D84.4 (VDD), D85.4 (VDD), D86.4 (VDD), D87.4 (VDD), D88.4 (VDD), D89.4 (VDD), D90.4 (VDD), D91.4 (VDD), D92.4 (VDD), D93.4 (VDD), D94.4 (VDD), D95.4 (VDD), D96.4 (VDD), D97.4 (VDD), D98.4 (VDD), D99.4 (VDD), D100.4 (VDD), U3.5 (VCC); also elsewhere on the board
GND: C20.2, C21.2, C22.2, C23.2, C24.2, C25.2, C26.2, C27.2, C28.2, C29.2, C30.2, C31.2, C32.2, C33.2, C34.2, C35.2, C36.2, C37.2, D84.2 (VSS), D85.2 (VSS), D86.2 (VSS), D87.2 (VSS), D88.2 (VSS), D89.2 (VSS), D90.2 (VSS), D91.2 (VSS), D92.2 (VSS), D93.2 (VSS), D94.2 (VSS), D95.2 (VSS), D96.2 (VSS), D97.2 (VSS), D98.2 (VSS), D99.2 (VSS), D100.2 (VSS), U3.1, U3.3 (GND); also elsewhere on the board
unnamed: D84.1 (DOUT), D85.3 (DIN)
unnamed: D84.3 (DIN), U3.4
unnamed: D85.1 (DOUT), D86.3 (DIN)
unnamed: D86.1 (DOUT), D87.3 (DIN)
unnamed: D87.1 (DOUT), D88.3 (DIN)
unnamed: D88.1 (DOUT), D89.3 (DIN)
unnamed: D89.1 (DOUT), D90.3 (DIN)
unnamed: D90.1 (DOUT), D91.3 (DIN)
unnamed: D91.1 (DOUT), D92.3 (DIN)
unnamed: D92.1 (DOUT), D93.3 (DIN)
unnamed: D93.1 (DOUT), D94.3 (DIN)
unnamed: D94.1 (DOUT), D95.3 (DIN)
unnamed: D95.1 (DOUT), D96.3 (DIN)
unnamed: D96.1 (DOUT), D97.3 (DIN)
unnamed: D97.1 (DOUT), D98.3 (DIN)
unnamed: D98.1 (DOUT), D99.3 (DIN)
unnamed: D99.1 (DOUT), D100.3 (DIN)
UGLED: U3.2; also elsewhere on the board

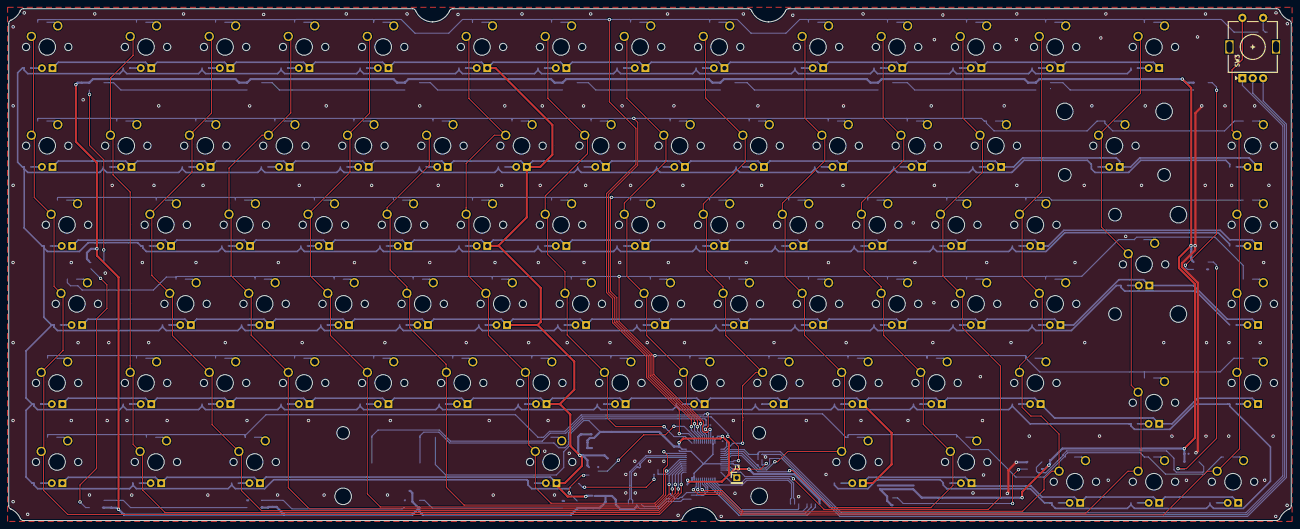
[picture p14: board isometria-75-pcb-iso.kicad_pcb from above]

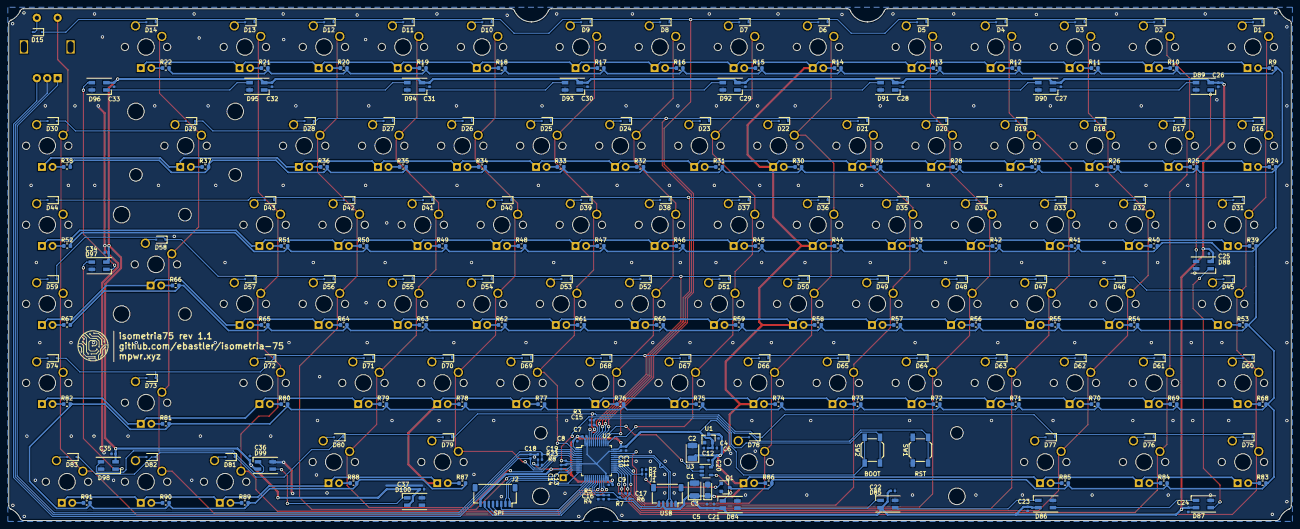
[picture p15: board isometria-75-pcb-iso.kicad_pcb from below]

Board: 2 copper layers, 308.3 x 123.0 mm, 320 parts (236 on the bottom side), 227 nets.

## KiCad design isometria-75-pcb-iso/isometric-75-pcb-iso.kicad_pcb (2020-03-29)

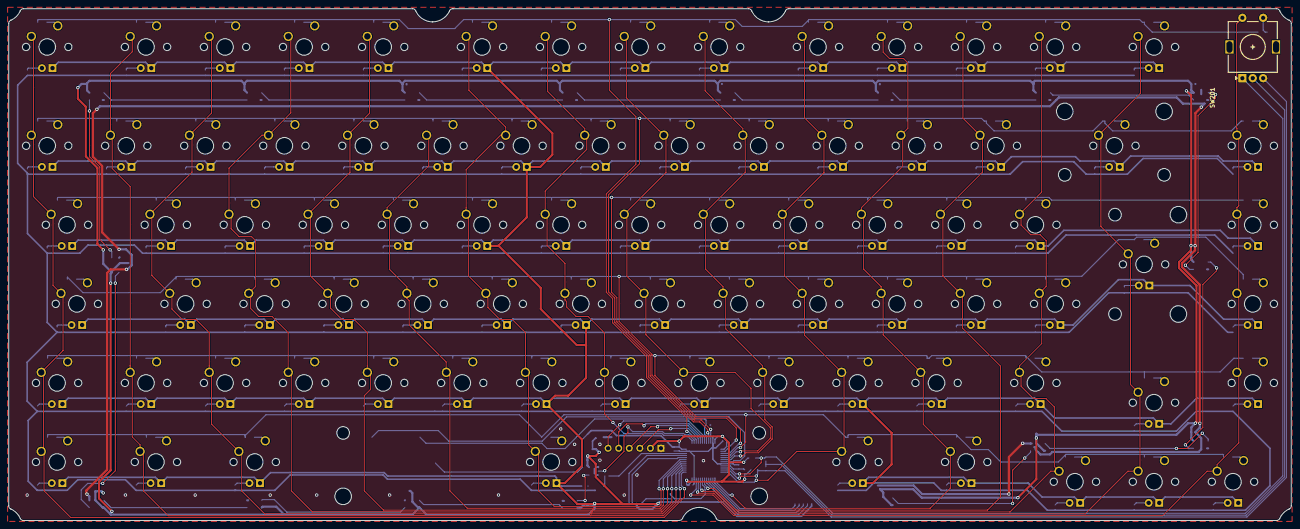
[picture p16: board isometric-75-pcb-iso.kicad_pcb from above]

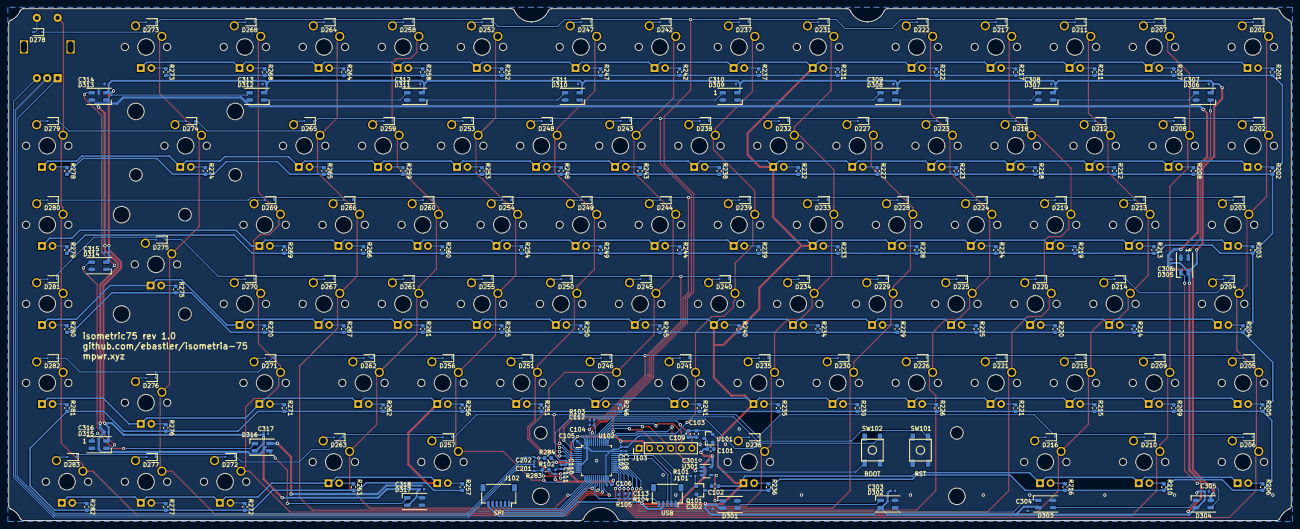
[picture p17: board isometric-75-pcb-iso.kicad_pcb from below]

Board: 2 copper layers, 308.3 x 123.0 mm, 314 parts (231 on the bottom side), 228 nets.

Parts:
C101, C102, C103, C109: 1u; C_0603_1608Metric
C104, C105, C106, C107, C110, C111, C112, C113, C201, C202, C301, C302, C303, C304, C305, C306, C307, C308, C309, C310, C311, C312, C313, C314, C315, C316, C317, C318: 100n; C_0402_1005Metric
C108: 1u; C_0402_1005Metric
D201, D202, D203, D204, D205, D206, D207, D208, D209, D210, D211, D212, D213, D214, D215, D216, D217, D218, D219, D220, D221, D222, D223, D224, D225, D226, D227, D228, D229, D230, D231, D232, D233, D234, D235, D236, D237, D238, D239, D240, D241, D242, D243, D244, D245, D246, D247, D248, D249, D250, D251, D252, D253, D254, D255, D256, D257, D258, D259, D260, D261, D262, D263, D264, D265, D266, D267, D268, D269, D270, D271, D272, D273, D274, D275, D276, D277, D278, D279, D280, D281, D282, D283: 1N4148; D_SOD-323F
D301, D302, D303, D304, D305, D306, D307, D308, D309, D310, D311, D312, D313, D314, D315, D316, D317: SK6812MINI; LED_SK6812MINI_PLCC4_3.5x3.5mm_P1.75mm
J101: USB; JST_SH_SM05B-SRSS-TB_1x05-1MP_P1.00mm_Horizontal
J102: SPI; JST_SH_SM06B-SRSS-TB_1x06-1MP_P1.00mm_Horizontal
J103: Conn_01x06_Male; PinHeader_1x06_P2.54mm_Vertical
MX201, MX202, MX207, MX208, MX209, MX211, MX212, MX213, MX214, MX215, MX217, MX218, MX219, MX220, MX221, MX222, MX223, MX224, MX225, MX226, MX227, MX228, MX229, MX230, MX231, MX232, MX233, MX234, MX235, MX237, MX238, MX239, MX240, MX241, MX242, MX243, MX244, MX245, MX246, MX247, MX248, MX249, MX250, MX251, MX252, MX253, MX254, MX255, MX256, MX258, MX259, MX260, MX261, MX262, MX264, MX265, MX266, MX267, MX268, MX269, MX270, MX272, MX273, MX276, MX277, MX278, MX279, MX280, MX281, MX282: MX-LED; MXOnly-1U
MX203, MX257, MX271: MX-LED; MXOnly-1.5U
MX204: MX-LED; MXOnly-1.75U
MX205, MX206, MX210, MX216, MX263: MX-LED; MXOnly-1.25U
MX236: MX-LED; MXOnly-6.25U
MX274: MX-LED; MXOnly-2U-ReversedStabilizers
MX275: MX-LED; MXOnly-ISO
Q101: AO3400A; SOT-23
R101, R102: 100; R_0402_1005Metric
R103: 10k; R_0402_1005Metric
R104, R105: 50k; R_0402_1005Metric
R201, R202, R203, R204, R205, R206, R207, R208, R209, R210, R211, R212, R213, R214, R215, R216, R217, R218, R219, R220, R221, R222, R223, R224, R225, R226, R227, R228, R229, R230, R231, R232, R233, R234, R235, R236, R237, R238, R239, R240, R241, R242, R243, R244, R245, R246, R247, R248, R249, R250, R251, R252, R253, R254, R255, R256, R257, R258, R259, R260, R261, R262, R263, R264, R265, R266, R267, R268, R269, R270, R271, R272, R273, R274, R275, R276, R277, R278, R279, R280, R281, R282: 680; R_0603_1608Metric
R283, R284: 10k; R_0603_1608Metric
SW101: RST; SKQG-1155865
SW102: BOOT; SKQG-1155865
SW201: Rotary_Encoder_Switch; RotaryEncoder_Alps_EC11E-Switch_Vertical_H20mm
U101: XC6206P332MR; SOT-23
U102: STM32F072CBTx; LQFP-48_7x7mm_P0.5mm
U301: 74LVC1G125; SOT-23-5

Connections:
+3V3: C103.1, C104.1, C105.1, C106.1, C107.1, C108.1, C109.1, J103.2, R102.1, R283.1, R284.2, SW102.1, U101.2, U102.1, U102.24, U102.36, U102.48
+5V: C101.1, C102.1, C301.1, C302.1, C303.1, C304.1, C305.1, C306.1, C307.1, C308.1, C309.1, C310.1, C311.1, C312.1, C313.1, C314.1, C315.1, C316.1, C317.1, C318.1, D301.4, D302.4, D303.4, D304.4, D305.4, D306.4, D307.4, D308.4, D309.4, D310.4, D311.4, D312.4, D313.4, D314.4, D315.4, D316.4, D317.4, J101.4, J102.6, MX201.4, MX202.4, MX203.4, MX204.4, MX205.4, MX206.4, MX207.4, MX208.4, MX209.4, MX210.4, MX211.4, MX212.4, MX213.4, MX214.4, MX215.4, MX216.4, MX217.4, MX218.4, MX219.4, MX220.4, MX221.4, MX222.4, MX223.4, MX224.4, MX225.4, MX226.4, MX227.4, MX228.4, MX229.4, MX230.4, MX231.4, MX232.4, MX233.4, MX234.4, MX235.4, MX236.4, MX237.4, MX238.4, MX239.4, MX240.4, MX241.4, MX242.4, MX243.4, MX244.4, MX245.4, MX246.4, MX247.4, MX248.4, MX249.4, MX250.4, MX251.4, MX252.4, MX253.4, MX254.4, MX255.4, MX256.4, MX257.4, MX258.4, MX259.4, MX260.4, MX261.4, MX262.4, MX263.4, MX264.4, MX265.4, MX266.4, MX267.4, MX268.4, MX269.4, MX270.4, MX271.4, MX272.4, MX273.4, MX274.4, MX275.4, MX276.4, MX277.4, MX278.4, MX279.4, MX280.4, MX281.4, MX282.4, U101.3, U301.5
COL0: MX201.1, MX202.1, MX203.1, MX204.1, MX205.1, MX206.1, U102.25
COL1: MX207.1, MX208.1, MX209.1, MX210.1, U102.26
COL2: MX211.1, MX212.1, MX213.1, MX214.1, MX215.1, MX216.1, U102.27
COL3: MX217.1, MX218.1, MX219.1, MX220.1, MX221.1, U102.28
COL4: MX222.1, MX223.1, MX224.1, MX225.1, MX226.1, U102.29
COL5: MX227.1, MX228.1, MX229.1, MX230.1, U102.30
COL6: MX231.1, MX232.1, MX233.1, MX234.1, MX235.1, MX236.1, U102.31
COL7: MX237.1, MX238.1, MX239.1, MX240.1, MX241.1, U102.37
COL8: MX242.1, MX243.1, MX244.1, MX245.1, MX246.1, U102.5
COL9: MX247.1, MX248.1, MX249.1, MX250.1, MX251.1, U102.6
COL10: MX252.1, MX253.1, MX254.1, MX255.1, MX256.1, MX257.1, U102.12
COL11: MX258.1, MX259.1, MX260.1, MX261.1, MX262.1, MX263.1, U102.13
COL12: MX264.1, MX265.1, MX266.1, MX267.1, U102.18
COL13: MX268.1, MX269.1, MX270.1, MX271.1, MX272.1, U102.20
COL14: MX273.1, MX274.1, MX275.1, MX276.1, MX277.1, U102.21
COL15: MX278.1, MX279.1, MX280.1, MX281.1, MX282.1, SW201.S2, U102.22
GND: C101.2, C102.2, C103.2, C104.2, C105.2, C106.2, C107.2, C108.2, C109.2, C110.2, C111.2, C112.2, C113.2, C201.1, C202.2, C301.2, C302.2, C303.2, C304.2, C305.2, C306.2, C307.2, C308.2, C309.2, C310.2, C311.2, C312.2, C313.2, C314.2, C315.2, C316.2, C317.2, C318.2, D301.2, D302.2, D303.2, D304.2, D305.2, D306.2, D307.2, D308.2, D309.2, D310.2, D311.2, D312.2, D313.2, D314.2, D315.2, D316.2, D317.2, J101.1, J102.1, J103.1, Q101.2, R103.2, R105.2, SW101.1, SW201.C, U101.1, U102.8, U102.23, U102.35, U102.47, U301.1, U301.3
LED-: Q101.3, R201.2, R202.2, R203.2, R204.2, R205.2, R206.2, R207.2, R208.2, R209.2, R210.2, R211.2, R212.2, R213.2, R214.2, R215.2, R216.2, R217.2, R218.2, R219.2, R220.2, R221.2, R222.2, R223.2, R224.2, R225.2, R226.2, R227.2, R228.2, R229.2, R230.2, R231.2, R232.2, R233.2, R234.2, R235.2, R236.2, R237.2, R238.2, R239.2, R240.2, R241.2, R242.2, R243.2, R244.2, R245.2, R246.2, R247.2, R248.2, R249.2, R250.2, R251.2, R252.2, R253.2, R254.2, R255.2, R256.2, R257.2, R258.2, R259.2, R260.2, R261.2, R262.2, R263.2, R264.2, R265.2, R266.2, R267.2, R268.2, R269.2, R270.2, R271.2, R272.2, R273.2, R274.2, R275.2, R276.2, R277.2, R278.2, R279.2, R280.2, R281.2, R282.2
LED_PWM: R101.1, U102.34
unnamed: C110.1, SW101.2, U102.7
unnamed: C111.1, R102.2, U102.9
unnamed: C112.1, R103.1, SW102.2, U102.44
unnamed: C113.1, R104.2, R105.1, U102.19
unnamed: D201.2, MX201.2
unnamed: D202.2, MX202.2
unnamed: D203.2, MX203.2
unnamed: D204.2, MX204.2
unnamed: D205.2, MX205.2
unnamed: D206.2, MX206.2
unnamed: D207.2, MX207.2
unnamed: D208.2, MX208.2
unnamed: D209.2, MX209.2
unnamed: D210.2, MX210.2
unnamed: D211.2, MX211.2
unnamed: D212.2, MX212.2
unnamed: D213.2, MX213.2
unnamed: D214.2, MX214.2
unnamed: D215.2, MX215.2
unnamed: D216.2, MX216.2
unnamed: D217.2, MX217.2
unnamed: D218.2, MX218.2
unnamed: D219.2, MX219.2
unnamed: D220.2, MX220.2
unnamed: D221.2, MX221.2
unnamed: D222.2, MX222.2
unnamed: D223.2, MX223.2
unnamed: D224.2, MX224.2
unnamed: D225.2, MX225.2
unnamed: D226.2, MX226.2
unnamed: D227.2, MX227.2
unnamed: D228.2, MX228.2
unnamed: D229.2, MX229.2
unnamed: D230.2, MX230.2
unnamed: D231.2, MX231.2
unnamed: D232.2, MX232.2
unnamed: D233.2, MX233.2
unnamed: D234.2, MX234.2
unnamed: D235.2, MX235.2
unnamed: D236.2, MX236.2
unnamed: D237.2, MX237.2
unnamed: D238.2, MX238.2
unnamed: D239.2, MX239.2
unnamed: D240.2, MX240.2
unnamed: D241.2, MX241.2
unnamed: D242.2, MX242.2
unnamed: D243.2, MX243.2
unnamed: D244.2, MX244.2
unnamed: D245.2, MX245.2
unnamed: D246.2, MX246.2
unnamed: D247.2, MX247.2
unnamed: D248.2, MX248.2
unnamed: D249.2, MX249.2
unnamed: D250.2, MX250.2
unnamed: D251.2, MX251.2
unnamed: D252.2, MX252.2
unnamed: D253.2, MX253.2
unnamed: D254.2, MX254.2
unnamed: D255.2, MX255.2
unnamed: D256.2, MX256.2
unnamed: D257.2, MX257.2
unnamed: D258.2, MX258.2
unnamed: D259.2, MX259.2
unnamed: D260.2, MX260.2
unnamed: D261.2, MX261.2
unnamed: D262.2, MX262.2
unnamed: D263.2, MX263.2
unnamed: D264.2, MX264.2
unnamed: D265.2, MX265.2
unnamed: D266.2, MX266.2
unnamed: D267.2, MX267.2
unnamed: D268.2, MX268.2
unnamed: D269.2, MX269.2
unnamed: D270.2, MX270.2
unnamed: D271.2, MX271.2
unnamed: D272.2, MX272.2
unnamed: D273.2, MX273.2
unnamed: D274.2, MX274.2
unnamed: D275.2, MX275.2
unnamed: D276.2, MX276.2
unnamed: D277.2, MX277.2
unnamed: D278.2, SW201.S1
unnamed: D279.2, MX278.2
unnamed: D280.2, MX279.2
unnamed: D281.2, MX280.2
unnamed: D282.2, MX281.2
unnamed: D283.2, MX282.2
unnamed: D301.1, D302.3
unnamed: D301.3, U301.4
unnamed: D302.1, D303.3
unnamed: D303.1, D304.3
unnamed: D304.1, D305.3
unnamed: D305.1, D306.3
unnamed: D306.1, D307.3
unnamed: D307.1, D308.3
unnamed: D308.1, D309.3
unnamed: D309.1, D310.3
unnamed: D310.1, D311.3
unnamed: D311.1, D312.3
unnamed: D312.1, D313.3
unnamed: D313.1, D314.3
unnamed: D314.1, D315.3
unnamed: D315.1, D316.3
unnamed: D316.1, D317.3
unnamed: MX201.3, R201.1
unnamed: MX202.3, R202.1
unnamed: MX203.3, R203.1
unnamed: MX204.3, R204.1
unnamed: MX205.3, R205.1
unnamed: MX206.3, R206.1
unnamed: MX207.3, R207.1
unnamed: MX208.3, R208.1
unnamed: MX209.3, R209.1
unnamed: MX210.3, R210.1
unnamed: MX211.3, R211.1
unnamed: MX212.3, R212.1
unnamed: MX213.3, R213.1
unnamed: MX214.3, R214.1
unnamed: MX215.3, R215.1
unnamed: MX216.3, R216.1
unnamed: MX217.3, R217.1
unnamed: MX218.3, R218.1
unnamed: MX219.3, R219.1
unnamed: MX220.3, R220.1
unnamed: MX221.3, R221.1
unnamed: MX222.3, R222.1
unnamed: MX223.3, R223.1
unnamed: MX224.3, R224.1
unnamed: MX225.3, R225.1
unnamed: MX226.3, R226.1
unnamed: MX227.3, R227.1
unnamed: MX228.3, R228.1
unnamed: MX229.3, R229.1
unnamed: MX230.3, R230.1
unnamed: MX231.3, R231.1
unnamed: MX232.3, R232.1
unnamed: MX233.3, R233.1
unnamed: MX234.3, R234.1
unnamed: MX235.3, R235.1
unnamed: MX236.3, R236.1
unnamed: MX237.3, R237.1
unnamed: MX238.3, R238.1
unnamed: MX239.3, R239.1
unnamed: MX240.3, R240.1
unnamed: MX241.3, R241.1
unnamed: MX242.3, R242.1
unnamed: MX243.3, R243.1
unnamed: MX244.3, R244.1
unnamed: MX245.3, R245.1
unnamed: MX246.3, R246.1
unnamed: MX247.3, R247.1
unnamed: MX248.3, R248.1
unnamed: MX249.3, R249.1
unnamed: MX250.3, R250.1
unnamed: MX251.3, R251.1
unnamed: MX252.3, R252.1
unnamed: MX253.3, R253.1
unnamed: MX254.3, R254.1
unnamed: MX255.3, R255.1
unnamed: MX256.3, R256.1
unnamed: MX257.3, R257.1
unnamed: MX258.3, R258.1
unnamed: MX259.3, R259.1
unnamed: MX260.3, R260.1
unnamed: MX261.3, R261.1
unnamed: MX262.3, R262.1
unnamed: MX263.3, R263.1
unnamed: MX264.3, R264.1
unnamed: MX265.3, R265.1
unnamed: MX266.3, R266.1
unnamed: MX267.3, R267.1
unnamed: MX268.3, R268.1
unnamed: MX269.3, R269.1
unnamed: MX270.3, R270.1
unnamed: MX271.3, R271.1
unnamed: MX272.3, R272.1
unnamed: MX273.3, R273.1
unnamed: MX274.3, R274.1
unnamed: MX275.3, R275.1
unnamed: MX276.3, R276.1
unnamed: MX277.3, R277.1
unnamed: MX278.3, R278.1
unnamed: MX279.3, R279.1
unnamed: MX280.3, R280.1
unnamed: MX281.3, R281.1
unnamed: MX282.3, R282.1
unnamed: Q101.1, R101.2
PB4: J103.3, U102.40
PB5: J103.4, U102.41
PB6_TX1: J103.5, U102.42
PB7_RX1: J103.6, U102.43
ROTA: C201.2, R283.2, SW201.B, U102.11
ROTB: C202.1, R284.1, SW201.A, U102.10
ROW0: D201.1, D207.1, D211.1, D217.1, D222.1, D231.1, D237.1, D242.1, D247.1, D252.1, D258.1, D264.1, D268.1, D273.1, D278.1, U102.39
ROW1: D202.1, D208.1, D212.1, D218.1, D223.1, D227.1, D232.1, D238.1, D243.1, D248.1, D253.1, D259.1, D265.1, D274.1, D279.1, U102.45
ROW2: D203.1, D213.1, D219.1, D224.1, D228.1, D233.1, D239.1, D244.1, D249.1, D254.1, D260.1, D266.1, D269.1, D280.1, U102.46
ROW3: D204.1, D214.1, D220.1, D225.1, D229.1, D234.1, D240.1, D245.1, D250.1, D255.1, D261.1, D267.1, D270.1, D275.1, D281.1, U102.2
ROW4: D205.1, D209.1, D215.1, D221.1, D226.1, D230.1, D235.1, D241.1, D246.1, D251.1, D256.1, D262.1, D271.1, D276.1, D282.1, U102.3
ROW5: D206.1, D210.1, D216.1, D236.1, D257.1, D263.1, D272.1, D277.1, D283.1, U102.4
SPI_MISO: J102.4, U102.16
SPI_MOSI: J102.5, U102.17
SPI_NSS: J102.2, U102.14
SPI_SCK: J102.3, U102.15
UGLED: U102.38, U301.2
USB-D+: J101.2, U102.33
USB-D-: J101.3, U102.32
Vsense: J101.5, R104.1

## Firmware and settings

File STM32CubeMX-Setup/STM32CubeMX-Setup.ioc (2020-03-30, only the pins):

Mcu.UserName=STM32F072CBTx
PA11.Signal=USB_DM
PA12.Signal=USB_DP
PA4.Signal=SPI1_NSS
PA5.Signal=SPI1_SCK
PA6.Signal=SPI1_MISO
PA7.Signal=SPI1_MOSI
PA9.Signal=S_TIM1_CH2
PB0.Signal=ADC_IN8
PB1.Signal=ADC_IN9
PB3.Signal=S_TIM2_CH2
PB6.Signal=I2C1_SCL
PB7.Signal=I2C1_SDA

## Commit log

2020-03-05 initialize project
    [isometric-75-pcb-iso.kicad_pcb, isometric-75-pcb-iso.sch]
2020-03-05 Add footprint libraries
2020-03-05 finished mc schematic
2020-03-05 added key matrix
    [isometric-75-pcb-iso.sch, matrix.sch]
2020-03-05 minor schematic changes
    [isometric-75-pcb-iso.sch]
2020-03-06 assigned footprints
    [isometric-75-pcb-iso.sch, matrix.sch]
2020-03-06 placing switches
    [isometric-75-pcb-iso.kicad_pcb]
2020-03-07 wired switches and leds
    [isometric-75-pcb-iso.kicad_pcb, isometric-75-pcb-iso.sch, matrix.sch]
2020-03-08 continued the pcb
    [isometric-75-pcb-iso.kicad_pcb, isometric-75-pcb-iso.sch, matrix.sch]
2020-03-12 more pcb wiring
    [isometric-75-pcb-iso.kicad_pcb, isometric-75-pcb-iso.sch, matrix.sch]
2020-03-13 connecting rows
    [Assem1.STEP, SM05B-SRSS-TB.STEP, SM06B-SRSS-TB.STEP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]
2020-03-13 finished wiring cols, changed jlc connector color
    [SM05B-SRSS-TB.STEP, SM06B-SRSS-TB.STEP, isometric-75-pcb-iso.kicad_pcb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]
2020-03-14 added underglow
    [SMD-WS2812B-Mini.step, isometric-75-pcb-iso.kicad_pcb, isometric-75-pcb-iso.sch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]
2020-03-14 added ground planes, various minor fixes
    [isometric-75-pcb-iso.kicad_pcb, isometric-75-pcb-iso.sch, matrix.sch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]
2020-03-15 cosmethical changes, fixed a footprint collision
    [isometric-75-pcb-iso.kicad_pcb, isometric-75-pcb-iso.sch, matrix.sch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]
2020-03-15 changed divider resistors to save power
    [isometric-75-pcb-iso.kicad_pcb, isometric-75-pcb-iso.sch]
2020-03-19 minor layout improvements
    [isometric-75-pcb-iso.kicad_pcb]
2020-03-24 minor layout fixes (thanks gLu3xb3rchi)
    [isometric-75-pcb-iso.kicad_pcb, isometric-75-pcb-iso.sch, matrix.sch]
2020-03-24 renamed +5V net (thanks gLu3xb3rchi)
    [isometric-75-pcb-iso.kicad_pcb]
2020-03-26 changed switch footprint to accomodate millmax 7305
    [isometric-75-pcb-iso.kicad_pcb]
2020-03-29 added pcb cutouts for mounting
    [isometric-75-pcb-iso.kicad_pcb]
2020-03-29 renamed folder
    [Assem1.STEP, SM05B-SRSS-TB.STEP, SM06B-SRSS-TB.STEP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]
2020-03-29 renamed pcb file, added 3d models
    [Switch.STEP, isometria-75-pcb-iso.kicad_pcb, isometria-75-pcb-iso.sch]
2020-03-29 rewired leds for better pcb edge clearance
    [isometria-75-pcb-iso.kicad_pcb]
2020-03-29 silkscreen improvements
    [isometria-75-pcb-iso.kicad_pcb]
2020-03-29 changed led backlight to a different pin
    [isometria-75-pcb-iso.kicad_pcb, isometria-75-pcb-iso.sch]
2020-03-29 moved UGLED to a HW PWM pin, improved some trace routing
    [isometria-75-pcb-iso.kicad_pcb, isometria-75-pcb-iso.sch]
2020-03-29 remove unused 3d model
    [isometria-75-pcb-iso.kicad_pcb]
2020-03-29 replaced a 3d model
    [isometria-75-pcb-iso.kicad_pcb]
2020-03-30 moved underglow from TIM1 to TIM2
    [isometria-75-pcb-iso.kicad_pcb, isometria-75-pcb-iso.sch]
2020-03-30 major schematic/pcb rework
    rewired SPI, added SPI CS/IRQ/RES pins, rewired part of the matrix in the process
    changed to a larger header for SPI
    added a divider for input voltage sensing
    removed extension header due to a lack of remaining unused GPIOs
    [isometria-75-pcb-iso.kicad_pcb, isometria-75-pcb-iso.sch, matrix.sch]
2020-03-31 added capacity, rerouted power traces
    [SM08B-SRSS-TB.STEP, isometria-75-pcb-iso.kicad_pcb, isometria-75-pcb-iso.sch]
2020-03-31 cosmetic silkscreen fixes
    [isometria-75-pcb-iso.kicad_pcb]
2020-03-31 fixed a groundplane error
    [isometria-75-pcb-iso.kicad_pcb]
2020-03-31 deleted unused text in the schematic
    [isometria-75-pcb-iso.sch]
2020-03-31 routed an unused GPIO to a solder pad
    could be used for possible expansion
    [isometria-75-pcb-iso.kicad_pcb, isometria-75-pcb-iso.sch]
2020-04-02 minor changes
    [isometria-75-pcb-iso.kicad_pcb]
2020-04-08 matched usb trace length
    [isometria-75-pcb-iso.kicad_pcb]
2020-04-13 some minor routing improvements
    [isometria-75-pcb-iso.kicad_pcb]
2020-04-13 moved power symbols
    [isometria-75-pcb-iso.sch]
2020-04-15 rerouted some traces
    [isometria-75-pcb-iso.kicad_pcb]
2020-04-15 moved some traces
    [isometria-75-pcb-iso.kicad_pcb]
2020-04-15 improved routing in a few places
    [isometria-75-pcb-iso.kicad_pcb]
2020-04-19 fixed silkscreen labels
    [isometria-75-pcb-iso.kicad_pcb]
2020-04-20 numerous minor improvements and fixes
    [isometria-75-pcb-iso.kicad_pcb]
2020-04-20 silkscreen fixes
    [isometria-75-pcb-iso.kicad_pcb]
2020-04-26 final touches
    changed some 0603 to 0402 for consistency, added vias to properly better ground planes, added LCSC part numbers for jlcpcb assembly
    [isometria-75-pcb-iso.kicad_pcb, isometria-75-pcb-iso.sch, matrix.sch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]
2020-04-26 moved silkscreen from vias
    [isometria-75-pcb-iso.kicad_pcb]
2020-04-27 improved componend value formatting
    [isometria-75-pcb-iso.sch, matrix.sch, underglow.sch]
2020-04-27 added manufacturing files
    [isometria-75-pcb-iso-B_Cu.gbr, isometria-75-pcb-iso-B_Mask.gbr, isometria-75-pcb-iso-B_Paste.gbr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]
2020-04-27 added BOM file
2020-05-09 added step + drawing for manufacturing
    [isometria-75-bottom.step, isometria-75-top.step]
2020-05-17 fixed label directions
    [isometria-75-pcb-iso.sch, matrix.sch]
2020-07-18 changed regulator symbol to submodule
    [isometria-75-pcb-iso.sch, matrix.sch, underglow.sch]
2020-10-11 removed unneccesary folder
    [SM05B-SRSS-TB.STEP, SM06B-SRSS-TB.STEP, SM08B-SRSS-TB.STEP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]
2020-10-11 fixed minor bugs, migrated to new libs
    [isometria-75-pcb-iso.kicad_pcb, isometria-75-pcb-iso.sch, matrix.sch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]
2020-10-11 added branding submodule
    [isometria-75-pcb-iso.kicad_pcb]
2020-10-11 added logo to pcb
    [isometria-75-pcb-iso.kicad_pcb]
2020-10-12 updated rev numbering
    [isometria-75-pcb-iso.kicad_pcb]
2020-10-12 updated gerbers, removed outdated PCBA
    [isometria-75-pcb-iso-B_Cu.gbr, isometria-75-pcb-iso-B_Mask.gbr, isometria-75-pcb-iso-B_SilkS.gbr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]
2020-10-24 added v2 pcb folder to gitignore of master
2020-10-24 removed unused renders, updated PCB renders
